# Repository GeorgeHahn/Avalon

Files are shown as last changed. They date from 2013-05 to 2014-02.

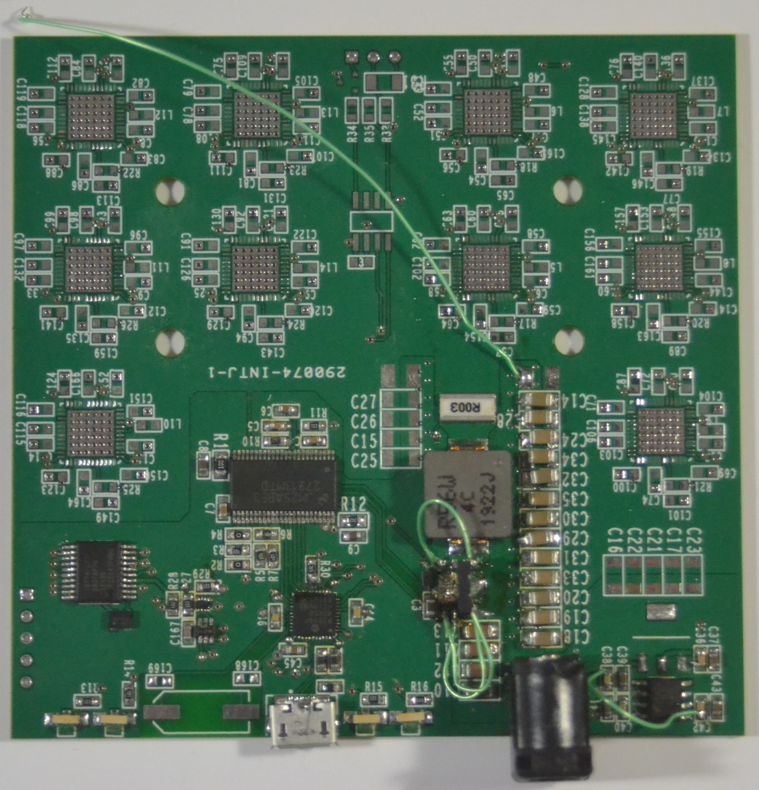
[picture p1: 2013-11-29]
img_top.JPG

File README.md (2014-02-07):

Avalon
========

Public Domain Bitcoin ASIC Miner Project

Firmware and driver based on Klondike Project

Donations: 14kf3rM66cLMrhR3eXHMjh4B5W5Xko1jJr

First prototype

## SUMMARY

  This is an open source effort to design and build a Bitcoin mining board based on the second generation Avalon ASIC. The final goal is to have a small board that holds 10 ASIC chips. This board can be controlled via USB communication. An example host would be a PC, Raspberry Pi or TP-Link WR703N router. The host will run cgminer with a custom driver based on the Klondike one and control the board via USB.

  A 10 chip board should be capable of 15000 MH/s and consume about 30W of power. Alternatively, the switching power supply onboard can be turned to a lower voltage, trading hashrate for power efficiency. The supply is variable from 0.700V to 1.708V. Each board can be easily powered by a low cost power adapter, like [this](http://www.amazon.com/gp/product/B005IUV60U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).

  Power for this board is supplied via a barrel jack connector (2.5mm ID, 5.5mm OD). For future revisions, Molex PCI-e or 4 pin power connectors may be added. Another limit on the first revision design is the data connection - these boards are USB only for now. In the future, CAN may be added to make it possible to chain multiple miners together.
  
  The design is currently in Cadence OrCAD + Allegro format, but will be completely backported to [Upverter](https://upverter.com/GeorgeHahn/0bb015271a32ca8e/Avalon/) once tested.

## STATUS

 - ☑ Layout
 - ▢ Prototype
  - ☑ PCB - First prototype has arrived
  - ☑ Stencil
  - ☑ Parts
  - ☑ Assembly
  - ▢ Debug first prototype - in progress
  
 - ▢ Initial firmware
  - ▢ Port Klondike firmware to PIC18F45K50
  - ▢ Testing with a Raspberry Pi
  - ▢ Tune settings for unique SMPS

 - ▢ Future
  - ▢ Try a prototype with metal substrate board (for better heat dissipation)
  - ▢ Measure current on 3.3v and 5v rails; switch to switching regulators if current is significant

## [SCHEMATIC](https://raw.github.com/GeorgeHahn/Avalon/master/hardware/Schematic.pdf) / [LAYOUT](https://github.com/GeorgeHahn/Avalon/tree/master/hardware/allegro/gerbers)
First prototype

## [ISSUES](https://github.com/GeorgeHahn/Avalon/issues)
First prototype has the following issues. Serious issues are bolded, optional improvements are italicized.

 - ▢ [#2](https://github.com/GeorgeHahn/Avalon/issues/2) **Switching FET (U21) has an incorrect footprint**
 - ▢ [#3](https://github.com/GeorgeHahn/Avalon/issues/3) **D1 and Q1 have suboptimal footprints**
 - ▢ [#4](https://github.com/GeorgeHahn/Avalon/issues/4) **C1 and C2 have incorrectly sized footprints**
 - ☑ [#5](https://github.com/GeorgeHahn/Avalon/issues/5) **Ground for some pins on U5 are not connected**
 - ▢ [#6](https://github.com/GeorgeHahn/Avalon/issues/6) Vcore SMPS overvoltage level should be set to A3255 maximum voltage (set by R3)
 - ☑ [#7](https://github.com/GeorgeHahn/Avalon/issues/7) Via-in-pads can be eliminated
 - ☑ [#8](https://github.com/GeorgeHahn/Avalon/issues/8) Status LEDs and D1 don't have polarity indicators on silkscreen
 - ▢ [#9](https://github.com/GeorgeHahn/Avalon/issues/9) Some parts are missing silkscreen reference designators
 - ☑ [#10](https://github.com/GeorgeHahn/Avalon/issues/10) The 3.3v regulator should take 5v input rather than VIN or be switched to a regulator that can handle higher input voltage
 - ▢ [#11](https://github.com/GeorgeHahn/Avalon/issues/11) *Barrel jack is a through hole part, should be switched to SMT*
 - ▢ [#12](https://github.com/GeorgeHahn/Avalon/issues/12) *Should have more input capacitors*
 - ▢ [#13](https://github.com/GeorgeHahn/Avalon/issues/13) *Should switch away from micro USB connectors for improved durability*
 - ☑ *Location for C2, C25-27, C15 is suboptimal*

## WARNINGS

  This project has an advanced switched mode power supply that can supply between 0.700V and 1.708V. NEVER set the SMPS above the Avalon ASICs' rated maximum voltage.

  This project is incomplete and in progress. There may be errors, mistakes, incomplete portions at this time. Do NOT use these project files to order circuit boards until they have been finished and confirmed to work.
  
  See LICENSE and COPYING files for terms and warranty disclaimer.
  
  See RELEASE NOTES for known problems, and issues.

## THANKS

Special thanks to [CUI Inc](http://www.cui.com/) for going the extra mile to get me a sample of their PJ-037BH connector. Thanks to TI for samples of ICs used in the SMPS module. Thanks to AVX for samples of the SMPS output capacitors.

Bitdeli Badge (https://bitdeli.com/free "Bitdeli Badge")

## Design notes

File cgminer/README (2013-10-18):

This is a multi-threaded multi-pool GPU, FPGA and ASIC miner with ATI GPU
monitoring, (over)clocking and fanspeed support for bitcoin and derivative
coins. Do not use on multiple block chains at the same time!

This code is provided entirely free of charge by the programmer in his spare
time so donations would be greatly appreciated. Please consider donating to the
address below.

Con Kolivas <kernel@kolivas.org>
15qSxP1SQcUX3o4nhkfdbgyoWEFMomJ4rZ

DOWNLOADS:

http://ck.kolivas.org/apps/cgminer

GIT TREE:

https://github.com/ckolivas/cgminer

Support thread:

http://bitcointalk.org/index.php?topic=28402.0

IRC Channel:

irc://irc.freenode.net/cgminer

License: GPLv3.  See COPYING for details.

SEE ALSO API-README, ASIC-README, FGPA-README, GPU-README AND SCRYPT-README FOR
MORE INFORMATION ON EACH.

---

EXECUTIVE SUMMARY ON USAGE:

After saving configuration from the menu, you do not need to give cgminer any
arguments and it will load your configuration.

Any configuration file may also contain a single
	"include" : "filename"
to recursively include another configuration file.
Writing the configuration will save all settings from all files in the output.

Single pool:

cgminer -o http://pool:port -u username -p password

Multiple pools:

cgminer -o http://pool1:port -u pool1username -p pool1password -o http://pool2:port -u pool2usernmae -p pool2password

Single pool with a standard http proxy, regular desktop:

cgminer -o "http:proxy:port|http://pool:port" -u username -p password

Single pool with a socks5 proxy, regular desktop:

cgminer -o "socks5:proxy:port|http://pool:port" -u username -p password

Single pool with stratum protocol support:

cgminer -o stratum+tcp://pool:port -u username -p password

The list of proxy types are:
 http:    standard http 1.1 proxy
 http0:   http 1.0 proxy
 socks4:  socks4 proxy
 socks5:  socks5 proxy
 socks4a: socks4a proxy
 socks5h: socks5 proxy using a hostname

If you compile cgminer with a version of CURL before 7.19.4 then some of the above will
not be available. All are available since CURL version 7.19.4

If you specify the --socks-proxy option to cgminer, it will only be applied to all pools
that don't specify their own proxy setting like above

---
BUILDING CGMINER

Dependencies:
	curl dev library 	http://curl.haxx.se/libcurl/
	(libcurl4-openssl-dev)

	curses dev library
	(libncurses5-dev or libpdcurses on WIN32)

	pkg-config		http://www.freedesktop.org/wiki/Software/pkg-config
	libtool			http://www.gnu.org/software/libtool/

	jansson			http://www.digip.org/jansson/
	(jansson is included in-tree and not necessary)

	AMD APP SDK		http://developer.amd.com/sdks/AMDAPPSDK
	(This sdk is mandatory for GPU mining)

	AMD ADL SDK		http://developer.amd.com/sdks/ADLSDK
	(This sdk is mandatory for ATI GPU monitoring & clocking)

	libudev headers
	(This is only required for ASIC+FPGA auto-detection and is linux only)

	libusb headers
	(This is only required for ASIC+FPGA support)

CGMiner specific configuration options:
	--disable-opencl        Override detection and disable building with opencl
	--disable-adl           Override detection and disable building with adl
	--enable-bflsc          Compile support for BFL ASICs (default disabled)
	--enable-klondike       Compile support for Klondike (default disabled)		
	--enable-bitforce       Compile support for BitForce FPGAs(default disabled)
	--enable-icarus         Compile support for Icarus bitstream FPGAs(default disabled)
	--enable-modminer       Compile support for ModMiner FPGAs(default disabled)
	--enable-ztex           Compile support for Ztex Board(default disabled)
	--enable-avalon         Compile support for Avalon (default disabled)
	--enable-scrypt         Compile support for scrypt litecoin mining (default disabled)
	--without-curses        Compile support for curses TUI (default enabled)

Basic *nix build instructions:
	To actually build:

	./autogen.sh	# only needed if building from git repo
	CFLAGS="-O2 -Wall -march=native" ./configure <options>

	No installation is necessary. You may run cgminer from the build
	directory directly.

Native WIN32 build instructions: see windows-build.txt

---

Usage instructions:  Run "cgminer --help" to see options:

Usage: . [-atDdGCgIKklmpPQqrRsTouvwOchnV] 
Options for both config file and command line:
--api-allow         Allow API access (if enabled) only to the given list of [W:]IP[/Prefix] address[/subnets]
                    This overrides --api-network and you must specify 127.0.0.1 if it is required
                    W: in front of the IP address gives that address privileged access to all api commands
--api-description   Description placed in the API status header (default: cgminer version)
--api-groups        API one letter groups G:cmd:cmd[,P:cmd:*...]
                    See API-README for usage
--api-listen        Listen for API requests (default: disabled)
                    By default any command that does not just display data returns access denied
                    See --api-allow to overcome this
--api-network       Allow API (if enabled) to listen on/for any address (default: only 127.0.0.1)
--api-port          Port number of miner API (default: 4028)
--auto-fan          Automatically adjust all GPU fan speeds to maintain a target temperature
--auto-gpu          Automatically adjust all GPU engine clock speeds to maintain a target temperature
--balance           Change multipool strategy from failover to even share balance
--benchmark         Run cgminer in benchmark mode - produces no shares
--compact           Use compact display without per device statistics
--debug|-D          Enable debug output
--device|-d <arg>   Select device to use, one value, range and/or comma separated (e.g. 0-2,4) default: all
--disable-rejecting Automatically disable pools that continually reject shares
--expiry|-E <arg>   Upper bound on how many seconds after getting work we consider a share from it stale (default: 120)
--failover-only     Don't leak work to backup pools when primary pool is lagging
--fix-protocol      Do not redirect to a different getwork protocol (eg. stratum)
--hotplug <arg>     Set hotplug check time to <arg> seconds (0=never default: 5) - only with libusb
--kernel-path|-K <arg> Specify a path to where bitstream and kernel files are (default: "/usr/local/bin")
--load-balance      Change multipool strategy from failover to efficiency based balance
--log|-l <arg>      Interval in seconds between log output (default: 5)
--lowmem            Minimise caching of shares for low memory applications
--monitor|-m <arg>  Use custom pipe cmd for output messages
--net-delay         Impose small delays in networking to not overload slow routers
--no-submit-stale   Don't submit shares if they are detected as stale
--pass|-p <arg>     Password for bitcoin JSON-RPC server
--per-device-stats  Force verbose mode and output per-device statistics
--protocol-dump|-P  Verbose dump of protocol-level activities
--queue|-Q <arg>    Minimum number of work items to have queued (0 - 10) (default: 1)
--quiet|-q          Disable logging output, display status and errors
--real-quiet        Disable all output
--remove-disabled   Remove disabled devices entirely, as if they didn't exist
--rotate <arg>      Change multipool strategy from failover to regularly rotate at N minutes (default: 0)
--round-robin       Change multipool strategy from failover to round robin on failure
--scan-time|-s <arg> Upper bound on time spent scanning current work, in seconds (default: 60)
--sched-start <arg> Set a time of day in HH:MM to start mining (a once off without a stop time)
--sched-stop <arg>  Set a time of day in HH:MM to stop mining (will quit without a start time)
--scrypt            Use the scrypt algorithm for mining (litecoin only)
--sharelog <arg>    Append share log to file
--shares <arg>      Quit after mining N shares (default: unlimited)
--socks-proxy <arg> Set socks4 proxy (host:port) for all pools without a proxy specified
--syslog            Use system log for output messages (default: standard error)
--temp-cutoff <arg> Temperature where a device will be automatically disabled, one value or comma separated list (default: 95)
--text-only|-T      Disable ncurses formatted screen output
--url|-o <arg>      URL for bitcoin JSON-RPC server
--user|-u <arg>     Username for bitcoin JSON-RPC server
--verbose           Log verbose output to stderr as well as status output
--userpass|-O <arg> Username:Password pair for bitcoin JSON-RPC server
Options for command line only:
--config|-c <arg>   Load a JSON-format configuration file
See example.conf for an example configuration.
--help|-h           Print this message
--version|-V        Display version and exit

GPU only options:

--auto-fan          Automatically adjust all GPU fan speeds to maintain a target temperature
--auto-gpu          Automatically adjust all GPU engine clock speeds to maintain a target temperature
--disable-gpu|-G    Disable GPU mining even if suitable devices exist
--gpu-threads|-g <arg> Number of threads per GPU (1 - 10) (default: 2)
--gpu-dyninterval <arg> Set the refresh interval in ms for GPUs using dynamic intensity (default: 7)
--gpu-engine <arg>  GPU engine (over)clock range in Mhz - one value, range and/or comma separated list (e.g. 850-900,900,750-850)
--gpu-fan <arg>     GPU fan percentage range - one value, range and/or comma separated list (e.g. 25-85,85,65)
--gpu-map <arg>     Map OpenCL to ADL device order manually, paired CSV (e.g. 1:0,2:1 maps OpenCL 1 to ADL 0, 2 to 1)
--gpu-memclock <arg> Set the GPU memory (over)clock in Mhz - one value for all or separate by commas for per card.
--gpu-memdiff <arg> Set a fixed difference in clock speed between the GPU and memory in auto-gpu mode
--gpu-powertune <arg> Set the GPU powertune percentage - one value for all or separate by commas for per card.
--gpu-reorder       Attempt to reorder GPU devices according to PCI Bus ID
--gpu-vddc <arg>    Set the GPU voltage in Volts - one value for all or separate by commas for per card.
--intensity|-I <arg> Intensity of GPU scanning (d or -10 -> 10, default: d to maintain desktop interactivity)
--kernel|-k <arg>   Override kernel to use (diablo, poclbm, phatk or diakgcn) - one value or comma separated
--ndevs|-n          Enumerate number of detected GPUs and exit
--no-restart        Do not attempt to restart GPUs that hang
--temp-hysteresis <arg> Set how much the temperature can fluctuate outside limits when automanaging speeds (default: 3)
--temp-overheat <arg> Overheat temperature when automatically managing fan and GPU speeds (default: 85)
--temp-target <arg> Target temperature when automatically managing fan and GPU speeds (default: 75)
--vectors|-v <arg>  Override detected optimal vector (1, 2 or 4) - one value or comma separated list
--worksize|-w <arg> Override detected optimal worksize - one value or comma separated list

See GPU-README for more information regarding GPU mining.

SCRYPT only options:

--lookup-gap <arg>  Set GPU lookup gap for scrypt mining, comma separated
--shaders <arg>     GPU shaders per card for tuning scrypt, comma separated
--thread-concurrency <arg> Set GPU thread concurrency for scrypt mining, comma separated

See SCRYPT-README for more information regarding litecoin mining.

ASIC and FPGA mining boards (BFL ASIC, BitForce, Icarus, ModMiner, Ztex)
only options:

--avalon-auto       Adjust avalon overclock frequency dynamically for best hashrate
--avalon-fan <arg> Set fanspeed percentage for avalon, single value or range (default: 20-100)
--avalon-freq <arg> Set frequency range for avalon-auto, single value or range
--avalon-cutoff <arg> Set avalon overheat cut off temperature (default: 60)
--avalon-options <arg> Set avalon options baud:miners:asic:timeout:freq
--avalon-temp <arg> Set avalon target temperature (default: 50)
--bfl-range         Use nonce range on bitforce devices if supported
--icarus-options <arg> Set specific FPGA board configurations - one set of values for all or comma separated
--icarus-timing <arg> Set how the Icarus timing is calculated - one setting/value for all or comma separated
--usb <arg>         USB device selection (See below)
--usb-dump          (See FPGA-README)

See FGPA-README and ASIC-README for more information regarding these.

Cgminer should automatically find all of your Avalon ASIC, BFL ASIC, BitForce
FPGAs, Icarus bitstream FPGAs, ASICMINER usb block erupters, ModMiner FPGAs,
or Ztex FPGAs

---

USB DEVICES

WINDOWS:

On windows, the direct USB support requires the installation of a WinUSB
driver (NOT the ftdi_sio driver), and attach it to your devices.
The easiest way to do this is to use the zadig utility which will install the
drivers for you and then once you plug in your device you can choose the
"list all devices" from the "option" menu and you should be able to see the
device as something like: "BitFORCE SHA256 SC". Choose the install or replace
driver option and select WinUSB. You can either google for zadig or download
it from the cgminer directoy in the DOWNLOADS link above.

LINUX:

On linux, the direct USB support requires no drivers at all. However due to
permissions issues, you may not be able to mine directly on the devices as a
regular user without giving the user access to the device or by mining as
root (administrator). In order to give your regular user access, you can make
him a member of the plugdev group with the following commands:

 sudo usermod -G plugdev -a `whoami`

If your distribution does not have the plugdev group you can create it with:

 sudo groupadd plugdev

In order for the BFL devices to instantly be owned by the plugdev group and
accessible by anyone from the plugdev group you can copy the file
"01-cgminer.rules" from the cgminer archive into the /etc/udev/rules.d
directory with the following command:

 sudo cp 01-cgminer.rules /etc/udev/rules.d/

After this you can either manually restart udev and re-login, or more easily
just reboot.

Advanced USB options:

The --usb option can restrict how many Avalon, BFL ASIC, BitForce FPGAs,
ModMiner FPGAs or Icarus bitstream FPGAs it finds:

  --usb 1:2,1:3,1:4,1:*
or
  --usb BAS:1,BFL:1,MMQ:0,ICA:0
or
  --usb :10

You can only use one of the above 3

The first version
  --usb 1:2,1:3,1:4,1:*
allows you to select which devices to mine on with a list of USB
 bus_number:device_address
All other USB devices will be ignored
Hotplug will also only look at the devices matching the list specified and
find nothing new if they are all in use
You can specify just the USB bus_number to find all devices like 1:*
which means any devices on USB bus_number 1
This is useful if you unplug a device then plug it back in the same port,
it usually reappears with the same bus_number but a different device_address

You can see the list of all USB devices on linux with 'sudo lsusb'
Cgminer will list the recognised USB devices with the '-n' option or the
'--usb-dump 0' option
The '--usb-dump N' option with a value of N greater than 0 will dump a lot
of details about each recognised USB device
If you wish to see all USB devices, include the --usb-list-all option

The second version
  --usb BAS:1,BFL:1,MMQ:0,ICA:0
allows you to specify how many devices to choose based on each device
driver cgminer has - there are currently 4 USB drivers: BAS, BFL, MMQ & ICA
N.B. you can only specify which device driver to limit, not the type of
each device, e.g. with BAS:n you can limit how many BFL ASIC devices will
be checked, but you cannot limit the number of each type of BFL ASIC
Also note that the MMQ count is the number of MMQ backplanes you have
not the number of MMQ FPGAs

The third version
  --usb :10
means only use a maximum of 10 devices of any supported USB devices
Once cgminer has 10 devices it will not configure any more and hotplug will
not scan for any more
If one of the 10 devices stops working, hotplug - if enabled, as is default
- will scan normally again until it has 10 devices

  --usb :0 will disable all USB I/O other than to initialise libusb

NOTE: The --device option will limit which devices are in use based on their
numbering order of the total devices, so if you hotplug USB devices regularly,
it will not reliably be the same devices.

---

WHILE RUNNING:

The following options are available while running with a single keypress:

[P]ool management [G]PU management [S]ettings [D]isplay options [Q]uit

P gives you:

Current pool management strategy: Failover
[F]ailover only disabled
[A]dd pool [R]emove pool [D]isable pool [E]nable pool
[C]hange management strategy [S]witch pool [I]nformation

S gives you:

[Q]ueue: 1
[S]cantime: 60
[E]xpiry: 120
[W]rite config file
[C]gminer restart

D gives you:

[N]ormal [C]lear [S]ilent mode (disable all output)
[D]ebug:off
[P]er-device:off
[Q]uiet:off
[V]erbose:off
[R]PC debug:off
[W]orkTime details:off
co[M]pact: off
[L]og interval:5

Q quits the application.

G gives you something like:

GPU 0: [124.2 / 191.3 Mh/s] [A:77  R:33  HW:0  U:1.73/m  WU 1.73/m]
Temp: 67.0 C
Fan Speed: 35% (2500 RPM)
Engine Clock: 960 MHz
Memory Clock: 480 Mhz
Vddc: 1.200 V
Activity: 93%
Powertune: 0%
Last initialised: [2011-09-06 12:03:56]
Thread 0: 62.4 Mh/s Enabled ALIVE
Thread 1: 60.2 Mh/s Enabled ALIVE

[E]nable [D]isable [R]estart GPU [C]hange settings
Or press any other key to continue

The running log shows output like this:

 [2012-10-12 18:02:20] Accepted f0c05469 Diff 1/1 GPU 0 pool 1
 [2012-10-12 18:02:22] Accepted 218ac982 Diff 7/1 GPU 1 pool 1
 [2012-10-12 18:02:23] Accepted d8300795 Diff 1/1 GPU 3 pool 1
 [2012-10-12 18:02:24] Accepted 122c1ff1 Diff 14/1 GPU 1 pool 1

The 8 byte hex value are the 2nd 8 bytes of the share being submitted to the
pool. The 2 diff values are the actual difficulty target that share reached
followed by the difficulty target the pool is currently asking for.

---
Also many issues and FAQs are covered in the forum thread
dedicated to this program,
	http://forum.bitcoin.org/index.php?topic=28402.0

The output line shows the following:
(5s):1713.6 (avg):1707.8 Mh/s | A:729  R:8  HW:0  WU:22.53/m

Each column is as follows:
5s:  A 5 second exponentially decaying average hash rate
avg: An all time average hash rate
A:  The total difficulty of Accepted shares
R:  The total difficulty of Rejected shares
HW:  The number of HardWare errors
WU:  The Work Utility defined as the number of diff1 shares work / minute
     (accepted or rejected).

 GPU 1: 73.5C 2551RPM | 427.3/443.0Mh/s | A:8 R:0 HW:0 WU:4.39/m

Each column is as follows:
Temperature (if supported)
Fanspeed (if supported)
A 5 second exponentially decaying average hash rate
An all time average hash rate
The total difficulty of accepted shares
The total difficulty of rejected shares
The number of hardware erorrs
The work utility defined as the number of diff1 shares work / minute

The cgminer status line shows:
 ST: 1  SS: 0  NB: 1  LW: 8  GF: 1  RF: 1

ST is STaged work items (ready to use).
SS is Stale Shares discarded (detected and not submitted so don't count as rejects)
NB is New Blocks detected on the network
LW is Locally generated Work items
GF is Getwork Fail Occasions (server slow to provide work)
RF is Remote Fail occasions (server slow to accept work)

The block display shows:
Block: 0074c5e482e34a506d2a051a...  Started: [17:17:22]  Best share: 2.71K

This shows a short stretch of the current block, when the new block started,
and the all time best difficulty share you've found since starting cgminer
this time.

---
MULTIPOOL

FAILOVER STRATEGIES WITH MULTIPOOL:
A number of different strategies for dealing with multipool setups are
available. Each has their advantages and disadvantages so multiple strategies
are available by user choice, as per the following list:

FAILOVER:
The default strategy is failover. This means that if you input a number of
pools, it will try to use them as a priority list, moving away from the 1st
to the 2nd, 2nd to 3rd and so on. If any of the earlier pools recover, it will
move back to the higher priority ones.

ROUND ROBIN:
This strategy only moves from one pool to the next when the current one falls
idle and makes no attempt to move otherwise.

ROTATE:
This strategy moves at user-defined intervals from one active pool to the next,
skipping pools that are idle.

LOAD BALANCE:
This strategy sends work to all the pools to maintain optimum load. The most
efficient pools will tend to get a lot more shares. If any pool falls idle, the
rest will tend to take up the slack keeping the miner busy.

BALANCE:
This strategy monitors the amount of difficulty 1 shares solved for each pool
and uses it to try to end up doing the same amount of work for all pools.

---
LOGGING

cgminer will log to stderr if it detects stderr is being redirected to a file.
To enable logging simply add 2>logfile.txt to your command line and logfile.txt
will contain the logged output at the log level you specify (normal, verbose,
debug etc.)

In other words if you would normally use:
./cgminer -o xxx -u yyy -p zzz
if you use
./cgminer -o xxx -u yyy -p zzz 2>logfile.txt
it will log to a file called logfile.txt and otherwise work the same.

There is also the -m option on linux which will spawn a command of your choice
and pipe the output directly to that command.

The WorkTime details 'debug' option adds details on the end of each line
displayed for Accepted or Rejected work done. An example would be:

 <-00000059.ed4834a3 M:X D:1.0 G:17:02:38:0.405 C:1.855 (2.995) W:3.440 (0.000) S:0.461 R:17:02:47

The first 2 hex codes are the previous block hash, the rest are reported in
seconds unless stated otherwise:
The previous hash is followed by the getwork mode used M:X where X is one of
P:Pool, T:Test Pool, L:LP or B:Benchmark,
then D:d.ddd is the difficulty required to get a share from the work,
then G:hh:mm:ss:n.nnn, which is when the getwork or LP was sent to the pool and
the n.nnn is how long it took to reply,
followed by 'O' on it's own if it is an original getwork, or 'C:n.nnn' if it was
a clone with n.nnn stating how long after the work was recieved that it was cloned,
(m.mmm) is how long from when the original work was received until work started,
W:n.nnn is how long the work took to process until it was ready to submit,
(m.mmm) is how long from ready to submit to actually doing the submit, this is
usually 0.000 unless there was a problem with submitting the work,
S:n.nnn is how long it took to submit the completed work and await the reply,
R:hh:mm:ss is the actual time the work submit reply was received

If you start cgminer with the --sharelog option, you can get detailed
information for each share found. The argument to the option may be "-" for
standard output (not advisable with the ncurses UI), any valid positive number
for that file descriptor, or a filename.

To log share data to a file named "share.log", you can use either:
./cgminer --sharelog 50 -o xxx -u yyy -p zzz 50>share.log
./cgminer --sharelog share.log -o xxx -u yyy -p zzz

For every share found, data will be logged in a CSV (Comma Separated Value)
format:
    timestamp,disposition,target,pool,dev,thr,sharehash,sharedata
For example (this is wrapped, but it's all on one line for real):
    1335313090,reject,
    ffffffffffffffffffffffffffffffffffffffffffffffffffffffff00000000,
    http://localhost:8337,GPU0,0,
    6f983c918f3299b58febf95ec4d0c7094ed634bc13754553ec34fc3800000000,
    00000001a0980aff4ce4a96d53f4b89a2d5f0e765c978640fe24372a000001c5
    000000004a4366808f81d44f26df3d69d7dc4b3473385930462d9ab707b50498
    f681634a4f1f63d01a0cd43fb338000000000080000000000000000000000000
    0000000000000000000000000000000000000000000000000000000080020000

---

RPC API

For RPC API details see the API-README file

---

FAQ

Q: Can I mine on servers from different networks (eg smartcoin and bitcoin) at
the same time?
A: No, cgminer keeps a database of the block it's working on to ensure it does
not work on stale blocks, and having different blocks from two networks would
make it invalidate the work from each other.

Q: Can I configure cgminer to mine with different login credentials or pools
for each separate device?
A: No.

Q: Can I put multiple pools in the config file?
A: Yes, check the example.conf file. Alternatively, set up everything either on
the command line or via the menu after startup and choose settings->write
config file and the file will be loaded one each startup.

Q: The build fails with gcc is unable to build a binary.
A: Remove the "-march=native" component of your CFLAGS as your version of gcc
does not support it.

Q: Can you implement feature X?
A: I can, but time is limited, and people who donate are more likely to get
their feature requests implemented.

Q: Work keeps going to my backup pool even though my primary pool hasn't
failed?
A: Cgminer checks for conditions where the primary pool is lagging and will
pass some work to the backup servers under those conditions. The reason for
doing this is to try its absolute best to keep the GPUs working on something
useful and not risk idle periods. You can disable this behaviour with the
option --failover-only.

Q: Is this a virus?
A: Cgminer is being packaged with other trojan scripts and some antivirus
software is falsely accusing cgminer.exe as being the actual virus, rather
than whatever it is being packaged with. If you installed cgminer yourself,
then you do not have a virus on your computer. Complain to your antivirus
software company. They seem to be flagging even source code now from cgminer
as viruses, even though text source files can't do anything by themself.

Q: Can you modify the display to include more of one thing in the output and
less of another, or can you change the quiet mode or can you add yet another
output mode?
A: Everyone will always have their own view of what's important to monitor.
The defaults are very sane and I have very little interest in changing this
any further.

Q: What are the best parameters to pass for X pool/hardware/device.
A: Virtually always, the DEFAULT parameters give the best results. Most user
defined settings lead to worse performance. The ONLY thing most users should
need to set is the Intensity for GPUs.

Q: What happened to CPU mining?
A: Being increasingly irrelevant for most users, and a maintenance issue, it is
no longer under active development and will not be supported. No binary builds
supporting CPU mining will be released. Virtually all remaining users of CPU
mining are as back ends for illegal botnets. The main reason cgminer is being
inappopriately tagged as a virus by antivirus software is due to the trojans
packaging a CPU mining capable version of it. There is no longer ANY CPU mining
code in cgminer. If you are mining bitcoin with CPU today, you are spending
1000x more in electricity costs than you are earning in bitcoin.

Q: GUI version?
A: No. The RPC interface makes it possible for someone else to write one
though.

Q: I'm having an issue. What debugging information should I provide?
A: Start cgminer with your regular commands and add -D -T --verbose and provide
the full startup output and a summary of your hardware, operating system, ATI
driver version and ATI stream version.

Q: Why don't you provide win64 builds?
A: Win32 builds work everywhere and there is precisely zero advantage to a
64 bit build on windows.

Q: Is it faster to mine on windows or linux?
A: It makes no difference. It comes down to choice of operating system for
their various features. Linux offers much better long term stability and
remote monitoring and security, while windows offers you overclocking tools
that can achieve much more than cgminer can do on linux.

Q: Can I mine with cgminer on a MAC?
A: cgminer will compile on OSX, but the performance of GPU mining is
compromised due to the opencl implementation on OSX, there is no temperature
or fanspeed monitoring, and the cooling design of most MACs, despite having
powerful GPUs, will usually not cope with constant usage leading to a high
risk of thermal damage. It is highly recommended not to mine on a MAC unless
it is to a USB device.

Q: I'm trying to mine litecoin but cgminer shows MH values instead of kH and
submits no shares?
A: Add the --scrypt parameter.

Q: I switch users on windows and my mining stops working?
A: That's correct, it does. It's a permissions issue that there is no known
fix for due to monitoring of GPU fanspeeds and temperatures. If you disable
the monitoring with --no-adl it should switch okay.

Q: My network gets slower and slower and then dies for a minute?
A; Try the --net-delay option.

Q: How do I tune for p2pool?
A: p2pool has very rapid expiration of work and new blocks, it is suggested you
decrease intensity by 1 from your optimal value, and decrease GPU threads to 1
with -g 1. It is also recommended to use --failover-only since the work is
effectively like a different block chain. If mining with a minirig, it is worth
adding the --bfl-range option.

Q: Are OpenCL kernels from other mining software useable in cgminer?
A: No, the APIs are slightly different between the different software and they
will not work.

Q: I run PHP on windows to access the API with the example miner.php. Why does
it fail when php is installed properly but I only get errors about Sockets not
working in the logs?
A: http://us.php.net/manual/en/sockets.installation.php

Q: What is a PGA?
A: At the moment, cgminer supports 4 FPGAs: BitForce, Icarus, ModMiner, and Ztex.
They are Field-Programmable Gate Arrays that have been programmed to do Bitcoin
mining. Since the acronym needs to be only 3 characters, the "Field-" part has
been skipped.

Q: What is an ASIC?
A: Cgminer currently supports 2 ASICs: Avalon and BitForce SC devices. They
are Application Specify Integrated Circuit devices and provide the highest
performance per unit power due to being dedicated to only one purpose.

Q: Can I mine scrypt with FPGAs or ASICs?
A: No.

Q: What is stratum and how do I use it?
A: Stratum is a protocol designed for pooled mining in such a way as to
minimise the amount of network communications, yet scale to hardware of any
speed. With versions of cgminer 2.8.0+, if a pool has stratum support, cgminer
will automatically detect it and switch to the support as advertised if it can.
Stratum uses direct TCP connections to the pool and thus it will NOT currently
work through a http proxy but will work via a socks proxy if you need to use
one. If you input the stratum port directly into your configuration, or use the
special prefix "stratum+tcp://" instead of "http://", cgminer will ONLY try to
use stratum protocol mining. The advantages of stratum to the miner are no
delays in getting more work for the miner, less rejects across block changes,
and far less network communications for the same amount of mining hashrate. If
you do NOT wish cgminer to automatically switch to stratum protocol even if it
is detected, add the --fix-protocol option.

Q: Why don't the statistics add up: Accepted, Rejected, Stale, Hardware Errors,
Diff1 Work, etc. when mining greater than 1 difficulty shares?
A: As an example, if you look at 'Difficulty Accepted' in the RPC API, the number
of difficulty shares accepted does not usually exactly equal the amount of work
done to find them. If you are mining at 8 difficulty, then you would expect on
average to find one 8 difficulty share, per 8 single difficulty shares found.
However, the number is actually random and converges over time, it is an average,
not an exact value, thus you may find more or less than the expected average.

Q: Why do the scrypt diffs not match with the current difficulty target?
A: The current scrypt block difficulty is expressed in terms of how many
multiples of the BTC difficulty it currently is (eg 28) whereas the shares of
"difficulty 1" are actually 65536 times smaller than the BTC ones. The diff
expressed by cgminer is as multiples of difficulty 1 shares.

Q: Can I make a donation in litecoin?
A: Yes, see SCRYPT-README for the address, but the author prefers bitcoin if
possible.

Q: My keyboard input momentarily pauses or repeats keys every so often on
windows while mining?
A: The USB implementation on windows can be very flaky on some hardware and
every time cgminer looks for new hardware to hotplug it it can cause these
sorts of problems. You can disable hotplug with:
--hotplug 0

Q: Can I use a proxy?
A: Proxies only work with the getwork and GBT protocols using the --proxy
command. If you wish to use a proxy with stratum, people have supported
success with various 3rd party tools like proxifier.

Q: What should my Work Utility (WU) be?
A: Work utility is the product of hashrate * luck and only stabilises over a
very long period of time. Assuming all your work is valid work, bitcoin mining
should produce a work utility of approximately 1 per 71.6MH. This means at
5GH you should have a WU of 5000 / 71.6 or ~ 69. You cannot make your machine
do "better WU" than this - it is luck related. However you can make it much
worse if your machine produces a lot of hardware errors producing invalid work.

---

This code is provided entirely free of charge by the programmer in his spare
time so donations would be greatly appreciated. Please consider donating to the
address below.

Con Kolivas <kernel@kolivas.org>
15qSxP1SQcUX3o4nhkfdbgyoWEFMomJ4rZ

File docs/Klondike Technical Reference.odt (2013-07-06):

Klondike Technical Reference

This document describes technical details and operation of the Klondike Bitcoin miners.

There are currently three related but different designs:

K1 (Nano) - a small USB dongle containing one Avalon ASIC.

K16 - a medium size 10cm x 10cm board containing 16 Avalon ASICs.

K64 - a 4-up chained panelization of the K16 design, 20cm x 20cm.

These designs are based on a PIC16LF1459 micro-controller with USB connectivity. This device is low-cost and has enough functionality to handle all the tasks required.

The following PIC hardware functions are utilized in the Klondike:

USB engine – with software stack support, provides for host control.

I2C engine – simple bus to communicate with chained boards.

USART – used to receive result data from the ASICs on board.

Timer0 – provide timing for ASIC work progress and housekeeping.

Timer1 – measure fan tachometer output for fan speed (K16,K64).

Timer2,PWM – provide fan speed control (K16,K64).

Temperature Sensor – for monitoring successful heat dissipation.

ADC – for measuring an external thermistor, as above (K16, K64).

I/O pins – send data to the ASIC chain, enable clock, drive an LED indicator.

Upon device start up the PIC is programmed to attach to a USB host as a device with serial emulation. If it cannot detect a USB host then it falls back on I2C for host control. It monitors both these channels until it can begin operation which consists of accepting commands from it's host master. These commands are described in detail in this document.

In addition to the PIC controller the Klondike board also contains suitable regulated power and primary clock generation for the ASICs on board. This consists of 1.2V core power, 3.3V I/O and PIC power, and 1.2V clock generator power. The 1.2V core and 3.3V power are provided using buck regulator switching technology. The 1.2V clock generator supply is provided by a linear regulator to isolate it from the core supply. The clock is provided by a high precision oscillator package, or optionally from the internal PIC clock generator.

The K1 design uses a buck regulator only for the 1.2V core supply. The other two supplies are provided by linear regulation. All three are derived from the USB 5V supply. The K16 / K64 source power from a 12V ATX type power supply.

PIC16LF1459 Pin Allocation

The following table indicates the use allocated to each PIC I/O pin.

Pin# | Name | Klondike Usage
19 | RA0 | USB D+
18 | RA1 | USB D-
4 | RA3 | Fan tachometer sense input (also MCLR to program)
3 | RA4 | CLK_EN enable ASIC clock (optionally CLK_OUT)
2 | RA5 | Drives LED for activity indication
13 | RB4 | I2C data to slaves (SDA)
12 | RB5 | ASIC REPORT data input (both banks)
11 | RB6 | I2C clock to slaves (SCL)
10 | RB7 | ASIC REPORT clock input (both banks)
16 | RC0 | ICSPDAT – programming data (otherwise unused)
15 | RC1 | ICSPCLK – programming clock (otherwise unused)
14 | RC2 | Analog input for Thermistor voltage
7 | RC3 | DIN_9N – config data to ASIC bank 2 - P
6 | RC4 | DIN_9P – config data to ASIC bank 2 - N
5 | RC5 | PWM output to control fan via Power MOSFET
8 | RC6 | DIN_6N – config data to ASIC bank 1 - P
9 | RC7 | DIN_6P – config data to ASIC bank 1 - N

Two Klondike board variants support either the SSOP 20-pin or QFN 20-pin packages.

Klondike Command Protocol

The Klondike device chain is controlled by a host master using a simple command protocol. Each command consists of:

<cmd> single char <address> 1 byte, followed any required data.

<address> is a single byte binary ID ranging from 0 up to <slaves>, and is always the first parameter after a command. Not shown in the table below for brevity.

Replies also start with the same <cmd><address> pattern, not shown.

Command | Code | Data | Reply
Identity | I | None. | <version><serial><product>
Status | S | None. | <state><chips><slaves><workque> <workid><temp><fanspeed> <hashcount><errorcount>
Config | C | <hashclock><temp target><temp critical><fan speed> or 0 binary to query only. | Updated data echoed back.
Work | W | <workid><midstate><data> | returns same as Status command
Abort | A | None. | returns same as Status command
Enable | E | 1 or 0 | returns same as Status command
Result | = | None (not sent by host). | <workid><nonce>

The following data values are used above:

Name | Data Type | Value
<version> | 1 byte, binary | Protocol Version: high nibble:major, low nibble:minor
<serial> | 4 byte, binary | Unique serial# as 32bit word.
<product> | StringZ. | Product Identifier eg. K1, K16, K64. Zero terminated. Max 8 chars.
<state> | 1 character | I (initializing), R (ready for work), W (working), D (disabled).
<chips> | 1 byte, binary | Count of chips on board (1 - 64).
<slaves> | 1 byte, binary | Count of slaves connected to this board (0 – 112).
<workqc> | 1 byte, binary | Number of work items in queue including current active job.
<temp> | 1 byte, binary | Temperature value. Needs conversion to degC via calc or lookup table.
<fan speed> | 1 byte, binary | Fan speed. Count of ticks for tach high period.
<hashclock> | 2 bytes, binary | ASIC clock speed in 0.5 MHz steps, eg. 600 => 300MHz
<temp target> | 1 byte, binary | Temperature to maintain by adjusting fan speed. See temp conversion info.
<temp critical> | 1 byte, binary | Temperature above which to disable work.
<fan speed> | 1 byte, binary | Force fan speed, value 0-255 controls power to fan.
<workid> | 1 byte, binary | Work ID, unique per device address.
<midstate> | 32 bytes, binary | Midstate value to hash.
<data> | 12 bytes, binary | Data value to hash.
<hashcount> | 2 bytes, binary | Number of hashes completed as count of 256,000 hash units.
<errorcount> | 2 byte, binary | Number of errors that occurred in result receiver.
<nonce> | 4 bytes, binary | Result value of hashing.

The provided ktest program allows manually testing commands and serves as a working example of very simple code to control the Klondike.

Preliminary Firmware Operation Details

( a more full description will follow once final development is completed )

Temperature

The value returned by protocol data is an analog device reading (ADC) not deg C. A lookup table could be used but also in capable processors a conversion using the natural log function ( ln ) is easy.

From the thermistor datasheet we have,

deg C = 1 / ( 1 / (To + 273.15) + ln(Rt/Ro) / 3987) – 273.15

where To is 25C, Ro is 2200, Rt is the thermistor resistance measured via the voltage divider network and given by

Rt = ADC * 1000 / (256 – ADC) and is independent of reference voltage.

Or, in C code from cgminer klondike driver:

return (double)1/((double)1/(25+273.15) +

log((double)temp*1000/(256-temp)/2200)/3987) - 273.15;

Note that the temperature is read from a thermistor near the U7 ASIC and so is not the internal temperature of the ASIC. An offset value should be applied that estimates the difference. This offset is undetermined at this time.

See the “Thermistor Lookup Table.ods” spreadsheet for example lookup and temperature conversion details.

ASIC Clock

ASIC clock speed is indicated in 0.5 MHz steps – double the MHz rate, eg.

282 → write 564

300 → write 600

Fan Speed

Fan tachometer readings in the status record are the measured high period in 170.667uS ticks. Since the maximum is 255 ticks that means a high period of 43,520 uS. Since there are two tachometer periods per RPM with 50% duty cycle that makes the lowest possible RPM reading,

1/(0.043350 *2 *2) * 60 secs/minute = 345 RPM.

Below this it should report zero as a rollover clears the count.

General equation for RPM is,

RPM = 87890 / count

Hash Timer

The code uses Timer0 as a hash timer to predict when new work should be pushed and time how much work was done if aborted.

Timer0 runs off the instruction clock at 12 MHz with a DIV 256 prescaler, making each count 21.3 uS. A count is loaded into Timer0 depending on ASIC hash clock speed such that each rollover occurs at close to 256,000 hash cycles. This makes counting rollovers as “ticks” useful for counting large hash values to a resolution of 256,000 – and potentially more accurate if the Timer0 value is checked, though that is not currently implemented.

For example, at 282MHz clock a value of (256-42) is set for Timer0 which causes a tick every 896 uS. This corresponds closely with 282,000,000 / 256,000 hashes completed (actually 252,672 hashes). This tick is counted to determine when new work should be pushed to the ASIC chain. The work tick value is dependent on how many ASICs are populated on each board.

The work tick value is also counted up to 256 to provide a “Slow Tick” for various housekeeping tasks such as updating fan speed, temperature and toggling the activity LED.

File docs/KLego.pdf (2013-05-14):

## Klondike 16 / 64 Modular Design

Klondike is designed to fit together in an unlimited tile arrangement. The pin headers located on the K16 board allow using a simple jumper blocks to join units and enable board to board communication without having to deal with cables and wiring hassles. One single mini-USB connector is all that is needed to control the array. Special repeater-jumpers can boost the I2C signal and allow more boards to be attached.

The diagram below shows how K16 units connect, and the flow of control communication via I2C pathways. The large red squares show how a K64 board is really just 4 x K16 already pre-connected on one board. Like a K16 the K64 is designed to also tile, with both other K64 and smaller K16 units.

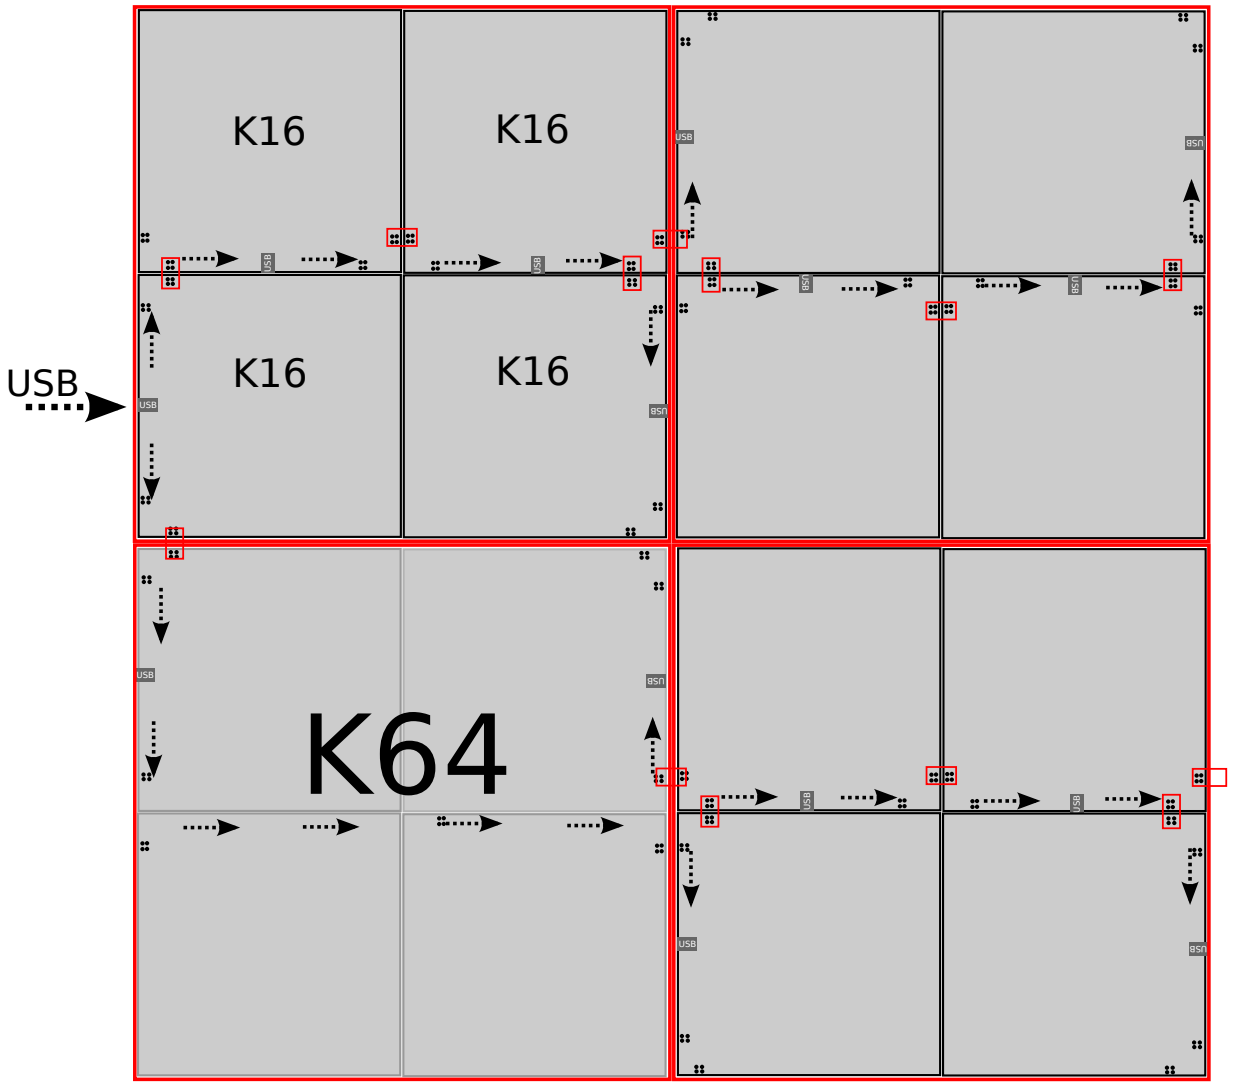
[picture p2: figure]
USB

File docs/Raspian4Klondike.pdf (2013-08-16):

Raspian for Klondike

Build and Install Notes

This SD card is based on the Raspian Server 2.4 image available from:

http://sirlagz.net/tag/raspbian-server-edition/

As indicated on that site I use dd to copy to the SD card, and then login and install packages needed for building and running cgminer. I've added a few other packages I find useful as well for small server monitoring. I've added some script files for auto-start of cgminer on boot up. I've also updated using apt-get upgrade.

After you plug the SD card into your RasPi and boot you will need to detect which IP address it is on. This can usually be found from your router client list or you can use the arp program from another system on the network.

arp a

eg. receive back,
? (10.42.0.83) at b8:27:eb:2e:18:61 [ether] on eth0

ssh pi@10.42.0.83
pwd:raspberry

I have already run the raspi-config program to set locale but you may want to run that program again and adjust any settings for your own use.

I configured the system to work with WiFi as well as basic LAN connections. You can edit your WiFi connection details in /etc/wpa_supplicant/wpa_supplicant.conf if you want to use a WiFi USB dongle for access.

The packages I installed for building cgminer are:

autoconf libtool libncurses-dev curl libcurl4-openssl-dev pkg-config libusb-1.0

I added htop and screen for a nicer process monitor and ease with detached sessions.

I haven't added the main klondike repo and ktest programs as typically those would be more useful on a full desktop for testing/development.

Useful Info:

You may want to change your password after logging in,

passwd

Or use ssh key authentication instead of passwords. From your host system, after you have password login working,

ssh-copy-id pi@<your hostname or IP>

If you want to disable password login edit /etc/sshd/sshd_config. And change,

PasswordAuthentication no

To pull an updated cgminer-klondike from the repo, and build,

cd cgminerklondike
git pull
make

The original commands used to configure cgminer and build were,

CFLAGS="g -O0 -W -Wall" ./autogen.sh –enableklondike
make
sudo make install

The default mining boot script uses “screen” to start a mining session that can be attached and detached from ssh as needed.

There is a bash alias set for attaching to the mining session,

alias mm='screen r Mining'
So simply typing mm<enter> will attach you, and Ctrl-A Ctrl-D will detach again.

Edit the ~/.cgminer/cgminer.conf file to suit your own pool server, or edit within cgminer and save the config. By default I have set my own donation server details and much appreciate any mining you happen to do for me.

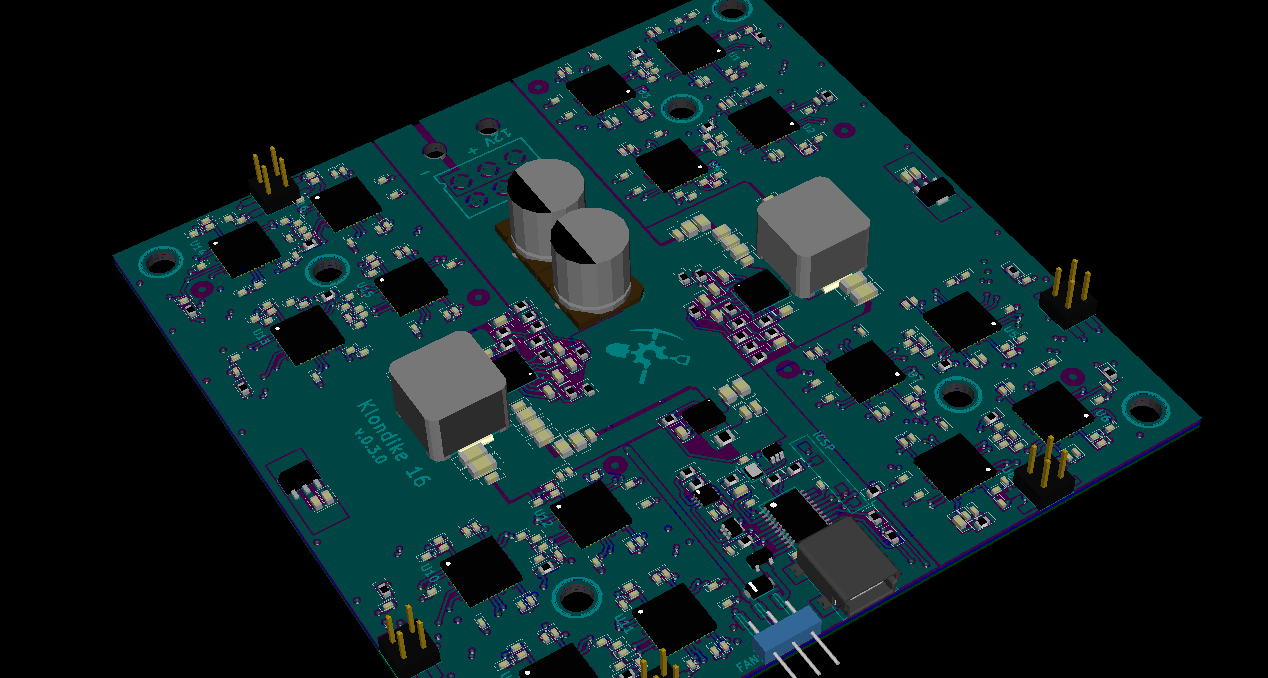
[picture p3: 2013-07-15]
docs/K16 3D.png

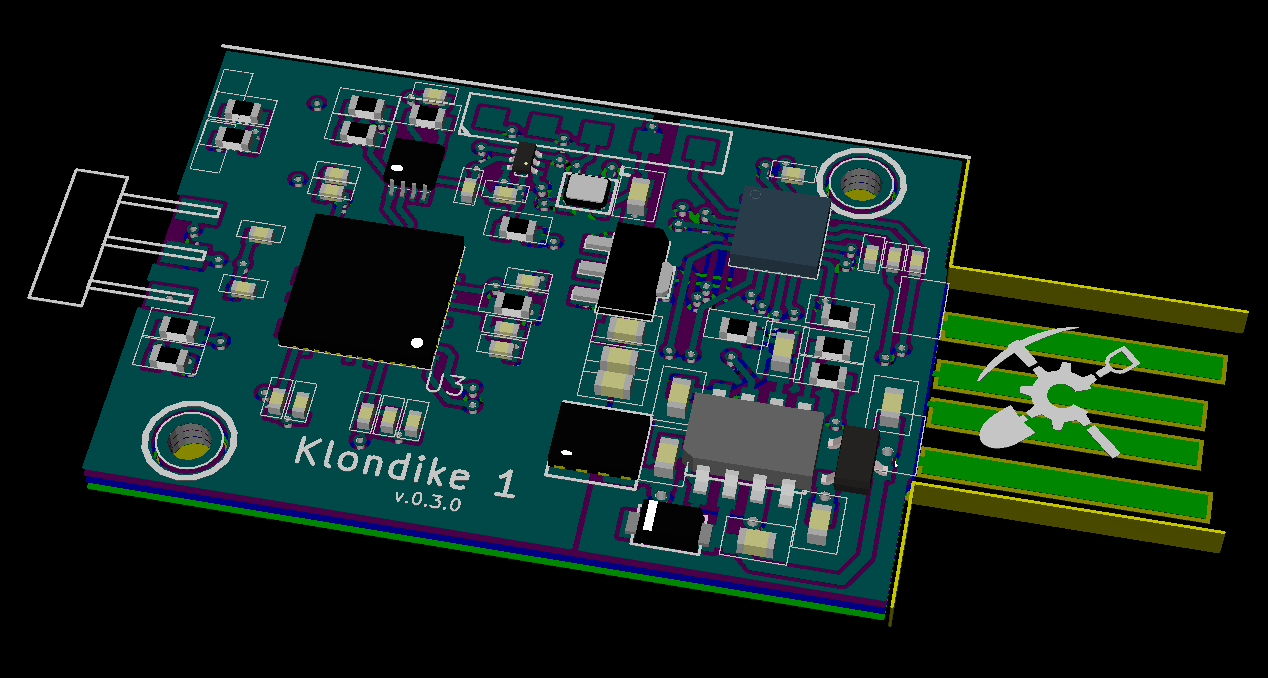
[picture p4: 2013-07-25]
docs/K1 Nano 3D.png

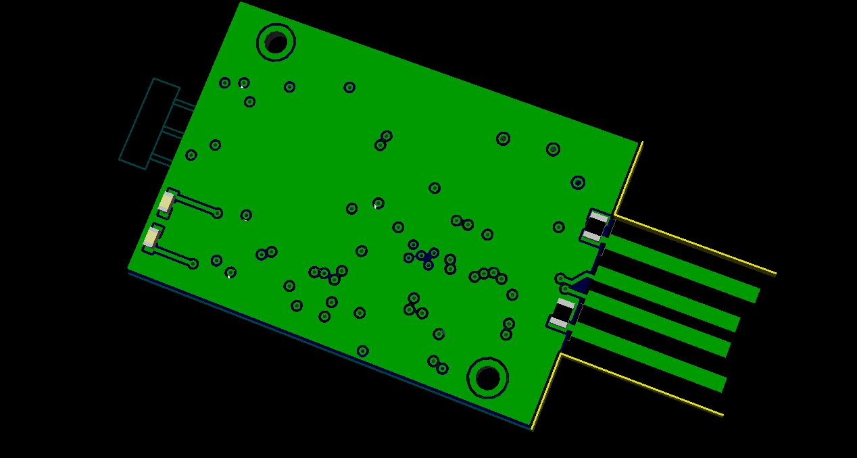
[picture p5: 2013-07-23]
docs/K1 Nano 3D Top.png

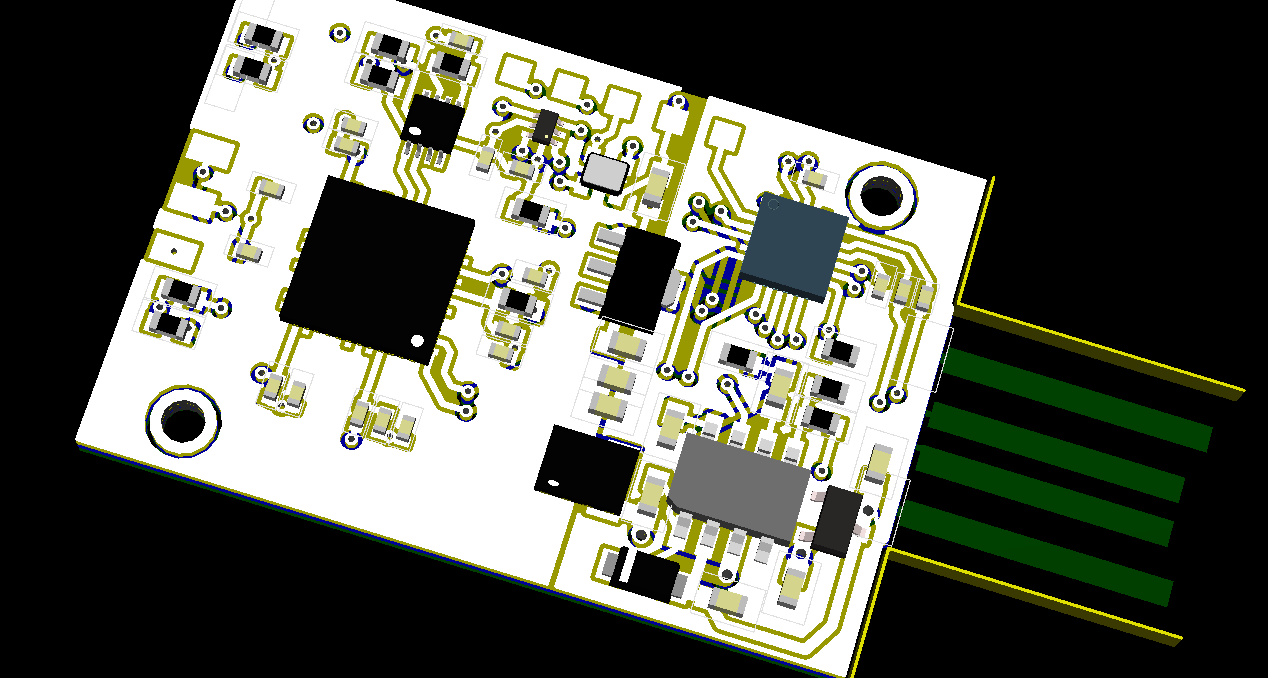
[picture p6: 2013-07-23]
docs/K1 Nano 3D White.png

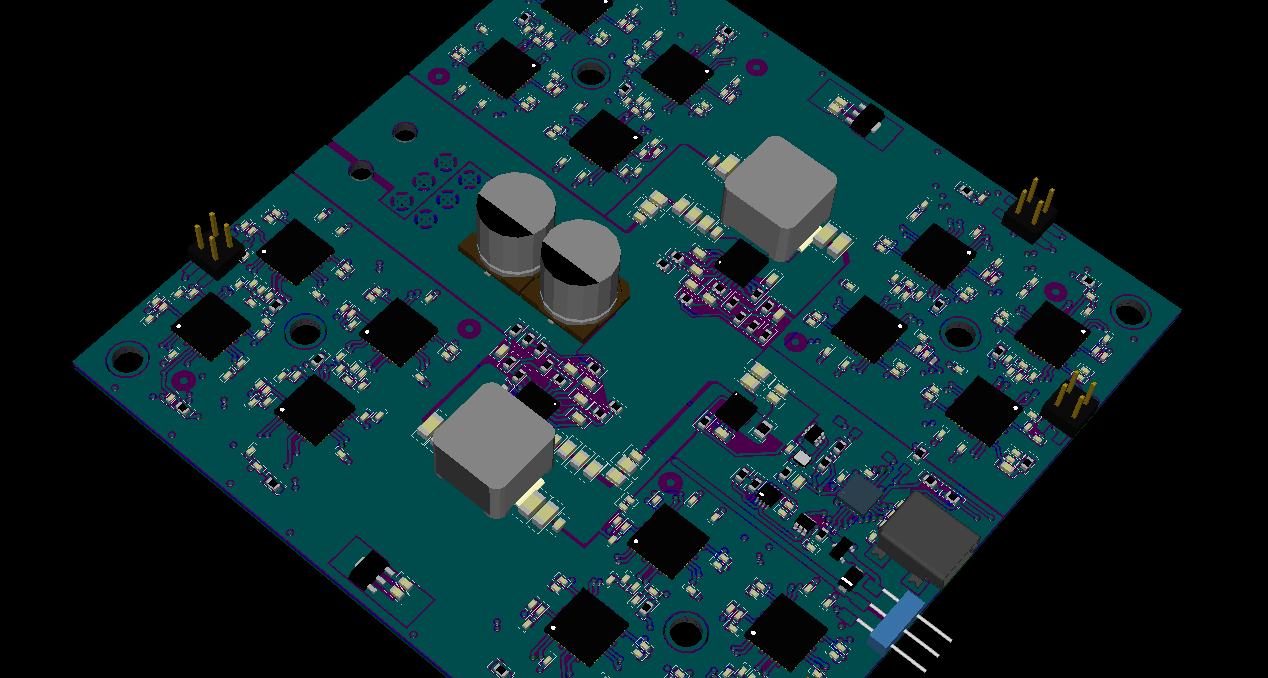
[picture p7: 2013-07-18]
docs/K16Q 3D.png

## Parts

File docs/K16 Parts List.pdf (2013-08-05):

## Klondike 16 – ASIC Miner Board

Part# | Description | Product # | MFR. | Value | Package | QTY | Qty 1 | Qty 25 | Qty 100 | Dist.
PCB | 4 Layer Circuit Board | PCB | China | 10cm x 10cm | | 1 | 9.000 | 5.000 | 2.700
U1-U16 | Avalon ASIC chip | AVALON | Avalon | | QFN48 | 16 | 0.000 | 0.000 | 0.000 | Avalon
U17 | USB Micro Controller | PIC16LF1459-I/SS | Microchip | | TSSOP-20 | 1 | 1.620 | 1.480 | 1.340 | Microchip
U17 | Alternate: USB Micro Controller | PIC16LF1459-I/ML | Microchip | | QFN20 | 0 | 1.660 | 1.520 | 1.380 | Microchip
U18-19 | 1.2V, 16A Buck Step Down Regulator | IR3895 | | 16A | PQFN-16 | 2 | 3.600 | 2.870 | 2.370 | Mouser
U20 | 3.3V, 1A Buck Step Down Regulator | MCP16321T-330E/NG | Microchip | 1A | VQFN-16 | 1 | 1.550 | 1.290 | 1.180 | Microchip
U21,U25 | Dual Schmitt Trigger Inverter | NL27WZ14DFT2G | On Semi. | | SOT-363 | 2 | 0.440 | 0.260 | 0.208 | Mouser
U22,U23 | 1.2V, 600mA LDO Regulator | AP7217D-12YG-13 | Diodes Inc. | 1.2V, 600mA | SOT-89-3L | 2 | 0.490 | 0.360 | 0.309
U24 | Dual NOR Gate | 74AUP2G02DC | NXP | | SOT-765-1 | 1 | 0.210 | 0.197 | 0.186 | Mouser
X1 | Oscillator | ASDMB-32.0-LC | | 32MHz | QFN4 | 1 | 1.690 | 1.430 | 1.010
Q1 | N-Channel MOSFET | NDS351AN | Fairchild | 1.4A, 30V | SSOT-3 | 1 | 0.230 | 0.199 | 0.171 | Mouser
D1 | Red LED (Data) | VLMS1300-GS08 | | 2V, 20mA | 0603 | 1 | 0.080 | 0.072 | 0.066 | Mouser
D2 | Green LED (Power) | VLMG1300-GS08 | | 2V, 20mA | 0603 | 1 | 0.080 | 0.076 | 0.070 | Mouser
D3 | | SL02-GS08 | | 1A, 30V | DO-219AB | 1 | 0.220 | 0.190 | 0.170 | Mouser
L1-2 | Power Inductor, Low DCR, 18A | 38L361C | | 0.360uH | 10x10 | 2 | 1.620 | 1.290 | 1.140 | Mouser
L3 | Power Inductor | MLP2016S4R7M | TDK | 4.7uH | 0806 | 1 | 0.290 | 0.273 | 0.236 | Mouser
L4-19 | Ferrite Bead Choke | ILBB0603ER600V | | 60 ohm, 25% | 0603 | 16 | 0.110 | 0.036 | 0.029 | Mouser
L20,L21 | Ferrite Bead Choke | BLM15BB121SN1D | | 120 ohm, 25% | 0402 | 2 | 0.240 | 0.105 | 0.060 | Mouser
L22,L23 | Ferrite Bead Choke | BLM15BB221SN1D | | 220 ohm, 25% | 0402 | 2 | 0.240 | 0.105 | 0.060 | Mouser
C19,C273 | Electrolytic Capacitor | UWT1V331MNL1GS | | 330uF | 10x10 | 2 | 0.165 | 0.132 | 0.132 | ES
C4-8,C23-27,C41,C42 | Ceramic Capacitor | GRM21BR61E106KA73L | | 10uF | 0805 | 12 | 0.218 | 0.179 | 0.130 | Mouser
C9-11,C28-30 | Ceramic Capacitor | GRM188R71E104KA01J | | 0.1uF | 0603 | 6 | 0.040 | 0.028 | 0.019 | Mouser
C3,C22 | Reference Capacitor | GRM1885C1H101JA01D | | 100pF | 0603 | 2 | 0.250 | 0.034 | 0.024 | Mouser
C16,C35 | Ceramic Capacitor | VJ0603Y332KXACW1BC | | 3300pF | 0603 | 2 | 0.060 | 0.050 | 0.040 | Mouser
C18,C37 | Ceramic Capacitor | VJ0603Y221MXJCW1BC | | 220pF | 0603 | 2 | 0.060 | 0.040 | 0.032 | Mouser
C12-15,C31-34 | Ceramic Capacitor | C3216X7S0J476M | TDK | 47uF | 1206 | 8 | 0.470 | 0.330 | 0.300 | Mouser
C2,C21 | Ceramic Capacitor | C1608X5R1V225M | TDK | 2.2uF | 0603 | 2 | 0.090 | 0.061 | 0.055 | Mouser
C17,C36 | Ceramic Capacitor | GRM188R71E103KA01J | | 10nF | 0603 | 2 | 0.200 | 0.027 | 0.018 | Mouser
C1,C20 | Ceramic Capacitor | GRM188R61E105KA12D | | 1.0uF | 0603 | 2 | 0.110 | 0.045 | 0.032 | Mouser
C38 | Ceramic Capacitor | VJ0603Y223KXACW1BC | | 22nF | 0603 | 1 | 0.080 | 0.060 | 0.050 | Mouser
C39,C40,C268-C271 | Ceramic Capacitor | C1608X5R0J226M | TDK | 22uF | 0603 | 6 | 0.150 | 0.117 | 0.106 | Mouser
C43-266 | Ceramic Capacitor | C1005X7S1A474K | TDK | 0.47uF | 0402 | 192 | 0.020 | 0.017 | 0.015 | Mouser
C272,C275 | Ceramic Capacitor | VJ0402Y103KXXAC | | 0.01uF | 0402 | 2 | 0.025 | 0.016 | 0.015 | Mouser
C274 | Ceramic Capacitor | GRM1555C1E300JA01D | | 30pF | 0402 | 1 | 0.250 | 0.034 | 0.024 | Mouser
C267,C276 | Ceramic Capacitor | GRM155R71C104KA88D | | 0.1uF | 0402 | 2 | 0.100 | 0.014 | 0.010 | Mouser
R8,R18 | Thick Film Resistor | ERJ-3EKF1781V | Panasonic | 1.78K 1% | 0603 | 2 | 0.070 | 0.020 | 0.003 | Mouser
R5,R9,R15,R19 | Thick Film Resistor | ERJ-3EKF4021V | Panasonic | 4.02K 1% | 0603 | 4 | 0.070 | 0.020 | 0.003 | Mouser
R7,R17,R10,R20 | Thick Film Resistor | ERJ-3EKF2871V | Panasonic | 2.87K 1% | 0603 | 4 | 0.070 | 0.020 | 0.003 | Mouser
R6,R16,R22,R43-44 | Thick Film Resistor | ERJ-3EKF1000V | Panasonic | 100 1% | 0603 | 5 | 0.070 | 0.020 | 0.003 | Mouser
R1,R11 | Thick Film Resistor | ERJ-3EKF3922V | Panasonic | 39.2K 1% | 0603 | 2 | 0.070 | 0.020 | 0.003 | Mouser
R3-4,R13-14 | Thick Film Resistor | ERJ-3EKF4992V | Panasonic | 49.9K 1% | 0603 | 4 | 0.070 | 0.020 | 0.003 | Mouser
R2,R12 | Thick Film Resistor | ERJ-3EKF7501V | Panasonic | 7.5K 1% | 0603 | 2 | 0.070 | 0.020 | 0.003 | Mouser
R21 | Thick Film Resistor | ERJ-3EKF1002V | Panasonic | 10K 1% | 0603 | 1 | 0.070 | 0.020 | 0.003 | Mouser
R23,R42,R45,R46,R48 | Thick Film Resistor | ERJ-3EKF1001V | Panasonic | 1K 1% | 0603 | 5 | 0.070 | 0.020 | 0.003 | Mouser
R24,R25 | Thick Film Resistor | ERJ-3EKF2201V | Panasonic | 2.2K 1% | 0603 | 2 | 0.070 | 0.020 | 0.003 | Mouser
R26-41 | Thick Film Resistor | ERJ-2RKF1003X | Panasonic | 100K | 0402 | 16 | 0.070 | 0.020 | 0.003 | Mouser
R47 | Thick Film Resistor | ERJ-2RKF1000X | Panasonic | 100 1% | 0402 | 1 | 0.070 | 0.020 | 0.003 | Mouser
RT1 | Thermistor | NCP15XW222J03RC | | 2.2K 5% | 0402 | 1 | 0.270 | 0.127 | 0.085 | Mouser
J1 | | 45718-0002 | | 6pin, 4.2mm | | 1 | 0.960 | 0.800 | 0.737 | Mouser
J1 | | 45558-0003 | | 6pin, 4.2mm | | 0 | 0.850 | 0.770 | 0.612 | Mouser
J1 | Alternate: Phoenix Terminal 2 pin | 1814634 or 1771091 | Phoenix | 6A, 2.5mm | SMD RA | 0 | 0.430 | 0.390 | 0.350 | Mouser
J2 | Mini USB Connector, Type B | 10033526-N3212MLF | FCI | 5pin | SMD | 1 | 0.450 | 0.430 | 0.390 | Mouser
J3,J5 | Pin Headers, SMD 4 pin Vertical | 14112 | 4UCONN | 2x2pin, 2.54mm | Vertical SMD | 4 | 0.089 | 0.089 | 0.089 | 4UCONN
J4 | Pin Header SMD, RA mount (FAN) | 11182 | 4UCONN | 3 pin, 2.54mm | RA SMD | 1 | 0.037 | 0.037 | 0.037 | 4UCONN
| | | | TOTAL | PER BOARD | 352 | 49.23 | 33.33 | 26.02
| | | | | SMD | 325
| | | | | QFN | 20
| | | | | Fine-Pitch | 1
| | | | | | 1
| | | | | Manual SMD | 5

Pricing was checked online but is a guide only and may not be accurate at the time of viewing.

Intl. Rect.

Digikey

Abracon | Digikey

Vishay
Vishay
Schottky Diode, Low Vf | Vishay

Murata

Vishay
Murata
Murata

Nichicon
Murata
Murata
Murata
Vishay
Vishay

Murata
Murata
Vishay

Vishay
Murata
Murata

Murata

Power Connector, MiniFitJr, PCIe | Molex | Thru-Hole
Alternate: Right Angle MiniFirJr, PCIe | Molex | Thru-Hole

Thru-Hole

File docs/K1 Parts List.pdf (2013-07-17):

Preliminary Parts List
| | | | | | | Cost | Cost | Cost
Part# | Description | Product # | MFR. | Value | Package | QTY | Qty 1 | Qty 25 | Qty 100 | Dist.
PCB | 4 Layer Circuit Board | PCB | China | 5cm x 2.5cm | | 1 | 2.500 | 0.900 | 0.600
U3 | Avalon ASIC chip | AVALON | Avalon | | QFN48 | 1 | 0.000 | 0.000 | 0.000 | Avalon
U2 | USB Micro Controller | PIC16LF1459-I/ML | Microchip | | QFN20 | 1 | 1.620 | 1.480 | 1.340 | Microchip
U1 | 1.2V, 2A Buck Step Down Regulator | AP6502A | Diodes Inc. | 2A | SOIC-8 | 1 | 0.930 | 0.728 | 0.351 | Mouser
U1 | Alternate: 1.2V, 3A Buck Reg | AP6503A | Diodes Inc. | 3A | SOIC-8 | 0 | 1.080 | 0.865 | 0.750 | Mouser
U4 | 3.3V, 250mA LDO Regulator | MCP1700T-3302E/TT | Microchip | 250mA | SOT-23 | 1 | 0.400 | 0.310 | 0.280 | Microchip
U4 | Alternate: AP7313-33 LDO Regulator | AP7313-33 | Diodes Inc. | 150mA | SOT-23R | 0 | 0.450 | 0.301 | 0.204 | Mouser
U5 | 1.2V, 600mA LDO Regulator | AP7217D-12YG-13 | Diodes Inc. | 600mA | SOT-89-3L | 1 | 0.490 | 0.360 | 0.309 | Mouser
U6 | Dual NOR Gate | 74AUP2G02DC | NXP | | SOT-765-1 | 1 | 0.210 | 0.197 | 0.186 | Mouser
U7 | Dual Schmitt Trigger Inverter | NL27WZ14DFT2G | On Semi. | | SOT-363 | 1 | 0.440 | 0.260 | 0.208 | Mouser
X1 | Oscillator | ASDMB-32.0-LC | | 32MHz | QFN4 | 1 | 1.690 | 1.430 | 1.010
D1 | | SL02-GS08 | | 1A, 30V | DO-219AB | 1 | 0.220 | 0.190 | 0.170 | Mouser
D2 | Red LED (Data) | VLMS1300-GS08 | | 2V, 20mA | 0603 | 1 | 0.080 | 0.072 | 0.066 | Mouser
D3 | Green LED (Power) | VLMG1300-GS08 | | 2V, 20mA | 0603 | 1 | 0.080 | 0.076 | 0.070 | Mouser
L1 | Power Inductor | SRN4018-3R3M | | 3.3uH, 2.2A | 4x4mm | 1 | 0.320 | 0.275 | 0.250 | Mouser
L1 | Alternate: Power Inductor | SRR6038-3R3Y | | 3.3uH, 3.5A | 6.8x6.8mm | 0 | 0.640 | 0.463 | 0.428 | Mouser
L2 | Ferrite Bead Choke | ILBB0603ER600V | | 60 ohm, 25% | 0603 | 1 | 0.110 | 0.036 | 0.029 | Mouser
L3,L4 | Ferrite Bead Choke | BLM15BB121SN1D | | 120 ohm, 300mA | 0402 | 2 | 0.240 | 0.105 | 0.060 | Mouser
L5,L6 | Ferrite Bead Choke | BLM21PG221SN1 | | 220 ohm, 2A | 0603 | 2 | 0.350 | 0.123 | 0.068 | Mouser
C1,C9-11 | Ceramic Capacitor | C1608X5R0J106M | TDK | 10uF | 0603 | 4 | 0.120 | 0.120 | 0.095 | Mouser
C2 | Ceramic Capacitor | GRM188R71E104KA01J | | 0.1uF | 0603 | 1 | 0.040 | 0.028 | 0.019 | Mouser
C4 | Ceramic Capacitor | VJ0603Y682KXXCW1BC | | 6.8nF | 0603 | 1 | 0.200 | 0.027 | 0.018 | Mouser
C5-6 | Ceramic Capacitor | C1608X5R0J226M | TDK | 22uF | 0603 | 2 | 0.150 | 0.117 | 0.106 | Mouser
C3,C7,C25 | Ceramic Capacitor | VJ0402Y103KXXAC | | 0.01uF | 0402 | 2 | 0.025 | 0.016 | 0.015 | Mouser
C12-23 | Ceramic Capacitor | C1005X7S1A474K | TDK | 0.47uF | 0402 | 12 | 0.020 | 0.017 | 0.015 | Mouser
C24 | Ceramic Capacitor | GRM1555C1E300JA01D | | 30pF | 0402 | 1 | 0.250 | 0.034 | 0.024 | Mouser
C8,C26 | Ceramic Capacitor | GRM155R71C104KA88D | | 0.1uF | 0402 | 2 | 0.100 | 0.014 | 0.010 | Mouser
R1 | Thick Film Resistor | ERJ-3EKF3001V | Panasonic | 3K | 0603 | 1 | 0.070 | 0.020 | 0.003 | Mouser
R2 | Thick Film Resistor | ERJ-3EKF1002V | Panasonic | 10K | 0603 | 1 | 0.070 | 0.020 | 0.003 | Mouser
R3 | Thick Film Resistor | ERJ-3EKF3241V | Panasonic | 3.24K | 0603 | 1 | 0.070 | 0.020 | 0.003 | Mouser
R4,R5,R9,R10,R12 | Thick Film Resistor | ERJ-3EKF1001V | Panasonic | 1K | 0603 | 5 | 0.070 | 0.020 | 0.003 | Mouser
R6 | Thick Film Resistor | ERJ-2RKF1003X | Panasonic | 100K | 0402 | 1 | 0.070 | 0.020 | 0.003 | Mouser
R7,R8,R11 | Thick Film Resistor | ERJ-3EKF1000V | Panasonic | 100 1% | 0603 | 3 | 0.070 | 0.020 | 0.003 | Mouser
RT1 | Thermistor | NCP15XW222J03RC | | 2.2K 5% | 0402 | 1 | 0.270 | 0.127 | 0.085 | Mouser
| | | | TOTAL | PER BOARD | 55 | 12.87 | 8.08 | 6.04

## Klondike 1 - Nano ASIC Miner

Pricing was checked online but is a guide only and may not be accurate at the time of viewing.

Abracon | Digikey
Schottky Diode, Low Vf | Vishay
Vishay
Vishay

Bourns
Bourns
Vishay
Murata
Murata

Murata
Vishay

Vishay

Murata
Murata

Murata

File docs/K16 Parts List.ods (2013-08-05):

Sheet: BOM
Klondike 16 – ASIC Miner Board
Pricing was checked online but is a guide only and may not be accurate at the time of viewing.
Part# | Description | Product # | MFR. | Value | Package | QTY | Qty 1 | Qty 25 | Qty 100 | Dist.
PCB | 4 Layer Circuit Board | PCB | China | 10cm x 10cm |  | 1 | 9.000 | 5.000 | 2.700
U1-U16 | Avalon ASIC chip | AVALON | Avalon |  | QFN48 | 16 | 0.000 | 0.000 | 0.000 | Avalon
U17 | USB Micro Controller | PIC16LF1459-I/SS | Microchip |  | TSSOP-20 | 1 | 1.620 | 1.480 | 1.340 | Microchip
U17 | Alternate: USB Micro Controller | PIC16LF1459-I/ML | Microchip |  | QFN20 | 0 | 1.660 | 1.520 | 1.380 | Microchip
U18-19 | 1.2V, 16A Buck Step Down Regulator | IR3895 | Intl. Rect. | 16A | PQFN-16 | 2 | 3.600 | 2.870 | 2.370 | Mouser
U20 | 3.3V, 1A Buck Step Down Regulator | MCP16321T-330E/NG | Microchip | 1A | VQFN-16 | 1 | 1.550 | 1.290 | 1.180 | Microchip
U21,U25 | Dual Schmitt Trigger Inverter | NL27WZ14DFT2G | On Semi. |  | SOT-363 | 2 | 0.440 | 0.260 | 0.208 | Mouser
U22,U23 | 1.2V, 600mA LDO Regulator | AP7217D-12YG-13 | Diodes Inc. | 1.2V, 600mA | SOT-89-3L | 2 | 0.490 | 0.360 | 0.309 | Digikey
U24 | Dual NOR Gate | 74AUP2G02DC | NXP |  | SOT-765-1 | 1 | 0.210 | 0.197 | 0.186 | Mouser
X1 | Oscillator | ASDMB-32.0-LC | Abracon | 32MHz | QFN4 | 1 | 1.690 | 1.430 | 1.010 | Digikey
Q1 | N-Channel MOSFET | NDS351AN | Fairchild | 1.4A, 30V | SSOT-3 | 1 | 0.230 | 0.199 | 0.171 | Mouser
D1 | Red LED (Data) | VLMS1300-GS08 | Vishay | 2V, 20mA | 0603 | 1 | 0.080 | 0.072 | 0.066 | Mouser
D2 | Green LED (Power) | VLMG1300-GS08 | Vishay | 2V, 20mA | 0603 | 1 | 0.080 | 0.076 | 0.070 | Mouser
D3 | Schottky Diode, Low Vf | SL02-GS08 | Vishay | 1A, 30V | DO-219AB | 1 | 0.220 | 0.190 | 0.170 | Mouser
L1-2 | Power Inductor, Low DCR, 18A | 38L361C | Murata | 0.360uH | 10x10 | 2 | 1.620 | 1.290 | 1.140 | Mouser
L3 | Power Inductor | MLP2016S4R7M | TDK | 4.7uH | 0806 | 1 | 0.290 | 0.273 | 0.236 | Mouser
L4-19 | Ferrite Bead Choke | ILBB0603ER600V | Vishay | 60 ohm, 25% | 0603 | 16 | 0.110 | 0.036 | 0.029 | Mouser
L20,L21 | Ferrite Bead Choke | BLM15BB121SN1D | Murata | 120 ohm, 25% | 0402 | 2 | 0.240 | 0.105 | 0.060 | Mouser
L22,L23 | Ferrite Bead Choke | BLM15BB221SN1D | Murata | 220 ohm, 25% | 0402 | 2 | 0.240 | 0.105 | 0.060 | Mouser
C19,C273 | Electrolytic Capacitor | UWT1V331MNL1GS | Nichicon | 330uF | 10x10 | 2 | 0.165 | 0.132 | 0.132 | ES
C4-8,C23-27,C41,C42 | Ceramic Capacitor | GRM21BR61E106KA73L | Murata | 10uF | 0805 | 12 | 0.218 | 0.179 | 0.130 | Mouser
C9-11,C28-30 | Ceramic Capacitor | GRM188R71E104KA01J | Murata | 0.1uF | 0603 | 6 | 0.040 | 0.028 | 0.019 | Mouser
C3,C22 | Reference Capacitor | GRM1885C1H101JA01D | Murata | 100pF | 0603 | 2 | 0.250 | 0.034 | 0.024 | Mouser
C16,C35 | Ceramic Capacitor | VJ0603Y332KXACW1BC | Vishay | 3300pF | 0603 | 2 | 0.060 | 0.050 | 0.040 | Mouser
C18,C37 | Ceramic Capacitor | VJ0603Y221MXJCW1BC | Vishay | 220pF | 0603 | 2 | 0.060 | 0.040 | 0.032 | Mouser
C12-15,C31-34 | Ceramic Capacitor | C3216X7S0J476M | TDK | 47uF | 1206 | 8 | 0.470 | 0.330 | 0.300 | Mouser
C2,C21 | Ceramic Capacitor | C1608X5R1V225M | TDK | 2.2uF | 0603 | 2 | 0.090 | 0.061 | 0.055 | Mouser
C17,C36 | Ceramic Capacitor | GRM188R71E103KA01J | Murata | 10nF | 0603 | 2 | 0.200 | 0.027 | 0.018 | Mouser
C1,C20 | Ceramic Capacitor | GRM188R61E105KA12D | Murata | 1.0uF | 0603 | 2 | 0.110 | 0.045 | 0.032 | Mouser
C38 | Ceramic Capacitor | VJ0603Y223KXACW1BC | Vishay | 22nF | 0603 | 1 | 0.080 | 0.060 | 0.050 | Mouser
C39,C40,C268-C271 | Ceramic Capacitor | C1608X5R0J226M | TDK | 22uF | 0603 | 6 | 0.150 | 0.117 | 0.106 | Mouser
C43-266 | Ceramic Capacitor | C1005X7S1A474K | TDK | 0.47uF | 0402 | 192 | 0.020 | 0.017 | 0.015 | Mouser
C272,C275 | Ceramic Capacitor | VJ0402Y103KXXAC | Vishay | 0.01uF | 0402 | 2 | 0.025 | 0.016 | 0.015 | Mouser
C274 | Ceramic Capacitor | GRM1555C1E300JA01D | Murata | 30pF | 0402 | 1 | 0.250 | 0.034 | 0.024 | Mouser
C267,C276 | Ceramic Capacitor | GRM155R71C104KA88D | Murata | 0.1uF | 0402 | 2 | 0.100 | 0.014 | 0.010 | Mouser
R8,R18 | Thick Film Resistor | ERJ-3EKF1781V | Panasonic | 1.78K 1% | 0603 | 2 | 0.070 | 0.020 | 0.003 | Mouser
R5,R9,R15,R19 | Thick Film Resistor | ERJ-3EKF4021V | Panasonic | 4.02K 1% | 0603 | 4 | 0.070 | 0.020 | 0.003 | Mouser
R7,R17,R10,R20 | Thick Film Resistor | ERJ-3EKF2871V | Panasonic | 2.87K 1% | 0603 | 4 | 0.070 | 0.020 | 0.003 | Mouser
R6,R16,R22,R43-44 | Thick Film Resistor | ERJ-3EKF1000V | Panasonic | 100 1% | 0603 | 5 | 0.070 | 0.020 | 0.003 | Mouser
R1,R11 | Thick Film Resistor | ERJ-3EKF3922V | Panasonic | 39.2K 1% | 0603 | 2 | 0.070 | 0.020 | 0.003 | Mouser
R3-4,R13-14 | Thick Film Resistor | ERJ-3EKF4992V | Panasonic | 49.9K 1% | 0603 | 4 | 0.070 | 0.020 | 0.003 | Mouser
R2,R12 | Thick Film Resistor | ERJ-3EKF7501V | Panasonic | 7.5K 1% | 0603 | 2 | 0.070 | 0.020 | 0.003 | Mouser
R21 | Thick Film Resistor | ERJ-3EKF1002V | Panasonic | 10K 1% | 0603 | 1 | 0.070 | 0.020 | 0.003 | Mouser
R23,R42,R45,R46,R48 | Thick Film Resistor | ERJ-3EKF1001V | Panasonic | 1K 1% | 0603 | 5 | 0.070 | 0.020 | 0.003 | Mouser
R24,R25 | Thick Film Resistor | ERJ-3EKF2201V | Panasonic | 2.2K 1% | 0603 | 2 | 0.070 | 0.020 | 0.003 | Mouser
R26-41 | Thick Film Resistor | ERJ-2RKF1003X | Panasonic | 100K | 0402 | 16 | 0.070 | 0.020 | 0.003 | Mouser
R47 | Thick Film Resistor | ERJ-2RKF1000X | Panasonic | 100 1% | 0402 | 1 | 0.070 | 0.020 | 0.003 | Mouser
RT1 | Thermistor | NCP15XW222J03RC | Murata | 2.2K 5% | 0402 | 1 | 0.270 | 0.127 | 0.085 | Mouser
J1 | Power Connector, MiniFitJr, PCIe | 45718-0002 | Molex | 6pin, 4.2mm | Thru-Hole | 1 | 0.960 | 0.800 | 0.737 | Mouser
J1 | Alternate: Right Angle MiniFirJr, PCIe | 45558-0003 | Molex | 6pin, 4.2mm | Thru-Hole | 0 | 0.850 | 0.770 | 0.612 | Mouser
J1 | Alternate: Phoenix Terminal 2 pin | 1814634 or 1771091 | Phoenix | 6A, 2.5mm | SMD RA | 0 | 0.430 | 0.390 | 0.350 | Mouser
J2 | Mini USB Connector, Type B | 10033526-N3212MLF | FCI | 5pin | SMD | 1 | 0.450 | 0.430 | 0.390 | Mouser
J3,J5 | Pin Headers, SMD 4 pin Vertical | 14112 | 4UCONN | 2x2pin, 2.54mm | Vertical SMD | 4 | 0.089 | 0.089 | 0.089 | 4UCONN
J4 | Pin Header SMD, RA mount (FAN) | 11182 | 4UCONN | 3 pin, 2.54mm | RA SMD | 1 | 0.037 | 0.037 | 0.037 | 4UCONN
 |  |  |  | TOTAL | PER BOARD | 352 | 49.23 | 33.33 | 26.02
 |  |  |  |  | SMD | 325
 |  |  |  |  | QFN | 20
 |  |  |  |  | Fine-Pitch | 1
 |  |  |  |  | Thru-Hole | 1
 |  |  |  |  | Manual SMD | 5

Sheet: Footprints
Klondike 16 – ASIC Miner Board
 |  |  |  | K16 | Datasheet
Part# | Description | Product # | Package | Library | Re-Verified
U1-U16 | Avalon ASIC chip | AVALON | QFN48 | QFN48 | Y
U17 | USB Micro Controller | PIC16LF1459-I/SS | TSSOP-20 | SSOP20 | Y
U17 | Alternate: USB Micro Controller | PIC16LF1459-I/ML | QFN20 | PIC16LF1459-ML | Y
U18-19 | 1.2V, 16A Buck Step Down Regulator | IR3895 | PQFN-16 | PQFN-16 | Y
U20 | 3.3V, 1A Buck Step Down Regulator | MCP16321T-330E/NG | VQFN-16 | QFN16 | Y
U21,U25 | Dual Schmitt Trigger Inverter | NL27WZ14DFT2G | SOT-363 | SOT-363 | Y
U22,U23 | 1.2V, 600mA LDO Regulator | AP7217D-12YG-13 | SOT-89-3L | SOT89-3L | Y
U24 | Dual NOR Gate | 74AUP2G02DC | SOT-765-1 | SOT765-1 | Y
X1 | Oscillator | ASDMB-32.0-LC | QFN4 | QFN48 | Y
Q1 | N-Channel MOSFET | NDS351AN | SSOT-3 | SSOT-3L | Y
D1 | Red LED (Data) | VLMS1300-GS08 | 0603 | D0603 | Y
D2 | Green LED (Power) | VLMG1300-GS08 | 0603 | D0603 | Y
D3 | Schottky Diode, Low Vf | SL02-GS08 | DO-219AB | DO219AB | Y
L1-2 | Power Inductor, Low DCR, 18A | 38L361C | 10x10 | 38L361C | Y
L3 | Power Inductor | MLP2016S4R7M | 0806 | L0805 | Y
L4-19 | Ferrite Bead Choke | ILBB0603ER600V | 0603 | L0603 | Y
L20,L21 | Ferrite Bead Choke | BLM15BB121SN1D | 402 | L0402 | Y
L22,L23 | Ferrite Bead Choke | BLM15BB221SN1D | 402 | L0402 | Y
C19,C273 | Electrolytic Capacitor | UWT1V331MNL1GS | 10x10 | Nichicon-10mm | Y
C4-8,C23-27,C41,C42 | Ceramic Capacitor | GRM21BR61E106KA73L | 0805 | C0805 | Y
C9-11,C28-30 | Ceramic Capacitor | GRM188R71E104KA01J | 0603 | C0603 | Y
C3,C22 | Reference Capacitor | GRM1885C1H101JA01D | 0603 | C0603 | Y
C16,C35 | Ceramic Capacitor | VJ0603Y332KXACW1BC | 0603 | C0603 | Y
C18,C37 | Ceramic Capacitor | VJ0603Y221MXJCW1BC | 0603 | C0603 | Y
C12-15,C31-34 | Ceramic Capacitor | C3216X7S0J476M | 1206 | C1206 | Y
C2,C21 | Ceramic Capacitor | C1608X5R1V225M | 0603 | C0603 | Y
C17,C36 | Ceramic Capacitor | GRM188R71E103KA01J | 0603 | C0603 | Y
C1,C20 | Ceramic Capacitor | GRM188R61E105KA12D | 0603 | C0603 | Y
C38 | Ceramic Capacitor | VJ0603Y223KXACW1BC | 0603 | C0603 | Y
C39,C40,C268-C271 | Ceramic Capacitor | C1608X5R0J226M | 0603 | C0603 | Y
C43-266 | Ceramic Capacitor | C1005X7S1A474K | 0402 | C0402 | Y
C272,C275 | Ceramic Capacitor | VJ0402Y103KXXAC | 0402 | C0402 | Y
C274 | Ceramic Capacitor | GRM1555C1E300JA01D | 0402 | C0402 | Y
C267,C276 | Ceramic Capacitor | GRM155R71C104KA88D | 0402 | C0402 | Y
R8,R18 | Thick Film Resistor | ERJ-3EKF1781V | 0603 | R0603 | Y
R5,R9,R15,R19 | Thick Film Resistor | ERJ-3EKF4021V | 0603 | R0603 | Y
R7,R17,R10,R20 | Thick Film Resistor | ERJ-3EKF2871V | 0603 | R0603 | Y
R6,R16,R22,R43-44,R47 | Thick Film Resistor | ERJ-3EKF1000V | 0603 | R0603 | Y
R1,R11 | Thick Film Resistor | ERJ-3EKF3922V | 0603 | R0603 | Y
R3-4,R13-14 | Thick Film Resistor | ERJ-3EKF4992V | 0603 | R0603 | Y
R2,R12 | Thick Film Resistor | ERJ-3EKF7501V | 0603 | R0603 | Y
R21 | Thick Film Resistor | ERJ-3EKF1002V | 0603 | R0603 | Y
R23,R42,R45,R46,R48 | Thick Film Resistor | ERJ-3EKF1001V | 0603 | R0603 | Y
R24,R25 | Thick Film Resistor | ERJ-3EKF2201V | 0603 | R0603 | Y
R26-41 | Thick Film Resistor | ERJ-2RKF1003X | 0402 | R0402 | Y
RT | Thermistor | NCP15XW222J03RC | 0402 | R0402 | Y
J1 | Power Connector, MiniFitJr, PCIe | 45718-0002 | Thru-Hole
J1 | Alternate: Right Angle MiniFirJr, PCIe | 45558-0003 | Thru-Hole
J1 | Alternate: Phoenix Terminal 2 pin | 1814634 or 1771091 | SMD RA
J2 | Mini USB Connector, Type B | 10033526-N3212MLF | SMD
J3,J5 | Pin Headers, SMD 4 pin Vertical | 14112 | Vertical SMD
J4 | Pin Header SMD, RA mount (FAN) | 11182 | RA SMD

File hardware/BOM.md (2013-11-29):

Open Source Bitcoin Miner  Revised: Tuesday, November 05, 2013
Drawn By: George Hahn          Revision: A

Bill Of Materials       November 12,2013      23:07:57	Page1

Item	Quantity	Reference	Part
______________________________________________

1.	[*330uF	cap_2917* **2x	C1,C2**](http://www.digikey.com/product-search/en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)
2.	[*22uF	cap_0603* **1x	C3**](http://www.digikey.com/product-detail/en/C1608X5R0J226M080AC/445-8028-1-ND/2792158)
3.	[*1200pF	cap_0603* **2x	C4,C5**](http://www.digikey.com/product-detail/en/GRM188R72A122KA01D/490-1474-1-ND/587849)
4.	[*0.1uF	cap_0603* **1x	C6**](http://www.digikey.com/product-detail/en/C1608X7R1H104K080AA/445-1314-1-ND/567687)
5.	[*0.022uF	cap_0603* **1x	C7**](http://www.digikey.com/product-detail/en/C1608X7R1H223K080AA/445-1312-1-ND/567696)
6.	[*1uF	cap_0603* **2x	C8,C9**](http://www.digikey.com/product-detail/en/TMK107BJ105KA-T/587-1248-1-ND/931025)
7.	[*4.7uF	cap_1206* **4x	C10,C11,C12,C13**](http://www.digikey.com/product-detail/en/C3216X5R1E475K115AB/445-14683-1-ND/3956349)
8.	[*22uF	cap_1206* **22x	C14,C15,C16,C17,C18,C19,
			C20,C21,C22,C23,C24,C25,
			C26,C27,C28,C29,C30,C31,
			C32,C33,C34,C35**](http://www.digikey.com/product-search/en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)
9.	[*0.01uF	cap_0603* **6x	C36,C38,C40,C42,C44,C46**](http://www.digikey.com/product-detail/en/CL10B103KB8NCNC/1276-1921-1-ND/3890007)
10.	[*4.7uF	cap_0603* **5x	C37,C39,C41,C43,C45**](http://www.digikey.com/product-detail/en/CL10B475KQ8NQNC/1276-2087-1-ND/3890173)
11.	[*0.47uF	cap_0603* **120x	C47,C48,C49,C50,C51,C52,
			C53,C54,C55,C56,C57,C58,
			C59,C60,C61,C62,C63,C64,
			C65,C66,C67,C68,C69,C70,
			C71,C72,C73,C74,C75,C76,
			C77,C78,C79,C80,C81,C82,
			C83,C84,C85,C86,C87,C88,
			C89,C90,C91,C92,C93,C94,
			C95,C96,C97,C98,C99,C100,
			C101,C102,C103,C104,C105,
			C106,C107,C108,C109,C110,
			C111,C112,C113,C114,C115,
			C116,C117,C118,C119,C120,
			C121,C122,C123,C124,C125,
			C126,C127,C128,C129,C130,
			C131,C132,C133,C134,C135,
			C136,C137,C138,C139,C140,
			C141,C142,C143,C144,C145,
			C146,C147,C148,C149,C150,
			C151,C152,C153,C154,C155,
			C156,C157,C158,C159,C160,
			C161,C162,C163,C164,C165,
			C166**](http://www.digikey.com/product-detail/en/CC0603KRX7R8BB473/311-1373-1-ND/2103157)
12.	[*30pF	cap_0603* **1x	C167**](http://www.digikey.com/product-detail/en/CL10C300JB8NNNC/1276-1021-1-ND/3889107)
13.	*XuF	cap_0603* **2x	C168,C169**
14.	[*CMDSH-3	SOD323* **1x	D1**](http://www.digikey.com/product-search/en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)
15.	[*LED	apa3010srcprv-gx* **4x	D2,D3,D4,D5**](http://www.digikey.com/product-search/en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)
16.	*Drill - Unplated M3	Part_drill_m3_33000mm* **4x	H1,H2,H3,H4**
17.	[*CUI PJ-037BH	CUI_PJ_037BH* **1x	J1**](http://www.digikey.com/product-search/en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)
18.	*ICSP	HEADER100_5* **1x	J2**
19.	[*Molex 0473460001	Molex_0473460001* **1x	J3**](http://www.digikey.com/product-search/en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)
20.	*FAN	header100_3* **1x	J4**
21.	[*560nH	ETQ-P4L* **1x	L1**](http://www.digikey.com/product-search/en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)
22.	[*BLM18HE102SN1D	ind_0603* **13x	L2,L3,L4,L5,L6,L7,L8,L9,
			L10,L11,L12,L13,L14**](http://www.digikey.com/product-search/en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)
23.	[*BC817-25-7-F	sot23* **1x	Q1**](http://www.digikey.com/product-search/en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)
24.	[*10	res_0805* **1x	R1**](http://www.digikey.com/product-detail/en/RMCF0805JT10R0/RMCF0805JT10R0CT-ND/1942532)
25.	[*0	res_0603* **2x	R2,R4**](http://www.digikey.com/product-detail/en/RMCF0603ZT0R00/RMCF0603ZT0R00CT-ND/1943218)
26.	[*5.11k	res_0603* **2x	R3,R5**](http://www.digikey.com/product-detail/en/RMCF0603FT5K11/RMCF0603FT5K11CT-ND/1943038)
28.	[*1.21k	res_0603* **1x	R6**](http://www.digikey.com/product-detail/en/RMCF0603FT1K21/RMCF0603FT1K21CT-ND/1943000)
29.	[*100k	res_0603* **11x	R7,R17,R18,R19,R20,R21,
			R22,R23,R24,R25,R26**](http://www.digikey.com/product-detail/en/RMCF0603JT100K/RMCF0603JT100KCT-ND/1943203)
30.	[*0.003	res_1225* **1x	R9**](http://www.digikey.com/product-search/en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)
31.	[*182	res_0603* **1x	R10**](http://www.digikey.com/product-detail/en/RMCF0603FT182R/RMCF0603FT182RCT-ND/2417953)
32.	[*100	res_0603* **2x	R11,R29**](http://www.digikey.com/product-detail/en/RMCF0603JT100R/RMCF0603JT100RCT-ND/1943156)
33.	[*2.2	res_0805* **1x	R12**](http://www.digikey.com/product-detail/en/RMCF0603JT2R20/RMCF0603JT2R20CT-ND/2418194)
34.	[*75-100	res_0603* **4x	R13,R14,R15,R16**](http://www.digikey.com/product-detail/en/RMCF0603JT100R/RMCF0603JT100RCT-ND/1943156)
35.	[*1k	res_0603* **2x	R27,R28**](http://www.digikey.com/product-detail/en/RMCF0603JT1K00/RMCF0603JT1K00CT-ND/1943173)
36.	[*40k	res_0603* **1x	R30**](http://www.digikey.com/product-detail/en/RMCF0603FT40K2/RMCF0603FT40K2CT-ND/1943095)
37.	[*1k, 1/4W	res_1206* **1x	R31**](http://www.digikey.com/product-detail/en/RMCF1206JT1K00/RMCF1206JT1K00CT-ND/1942786)
38.	[*13k	res_0603* **1x	R32**](http://www.digikey.com/product-detail/en/RMCF0603FT13K0/RMCF0603FT13K0CT-ND/1943065)
39.	[*10k	res_0603* **1x	R33**](http://www.digikey.com/product-detail/en/RMCF0603JT10K0/RMCF0603JT10K0CT-ND/1943191)
40.	[*10	res_0603* **1x	R34**](http://www.digikey.com/product-detail/en/RMCF0603JT10R0/RMCF0603JT10R0CT-ND/1943148)
41.	[*470	res_0603* **1x	R35**](http://www.digikey.com/product-detail/en/RMCF0603JT470R/RMCF0603JT470RCT-ND/1943166)
42.	[*LM27213	DGG* **1x	U1**](http://www.digikey.com/product-detail/en/LM27213MTD%2FNOPB/LM27213MTD%2FNOPB-ND/1871068)
43.	[*AP1117IE33G-13	sot224* **1x	U3**](http://www.digikey.com/product-search/en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)
44.	[*KA78L05AIDTF	8-soic* **1x	U4**](http://www.digikey.com/product-search/en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)
45.	[*IDT74FCT3807APYG	20-ssop* **1x	U5**](http://www.digikey.com/product-search/en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)
46.	[*ASDMB-25.000MHz	4-smd-dfnllc* **1x	U6**](http://www.digikey.com/product-detail/en/ASDMB-25.000MHZ-LC-T/535-11730-1-ND/2809943)
47.	[*PIC18F45K50	40-ufqfn* **1x	U7**](http://www.digikey.com/product-detail/en/PIC18F45K50-I%2FMV/PIC18F45K50-I%2FMV-ND/3671504)
48.	*BitSyncom A3255Q48	QFN48* **10x	U8,U9,U10,U11,U12,U13,
			U14,U15,U16,U17**
49.	[*74AUP2G02GF,115	8-xson* **1x	U18**](http://www.digikey.com/product-search/en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)
50.	[*NL27WZ14DFT2G	sc-88* **1x	U19**](http://www.digikey.com/product-search/en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)
51.	[*LM63	TI_D_R_PDSO_G8* **1x	U20**](http://www.digikey.com/product-detail/en/LM63CIMAX%2FNOPB/LM63CIMAX%2FNOPBCT-ND/3527023)
52.	[*CSD86350Q5D	QFN127P600X500X150-9N* **1x	U21**](http://www.digikey.com/product-search/en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)
53.	[*CRYSTAL	hc49_us* **1x	Y1**](http://www.digikey.com/product-search/en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)

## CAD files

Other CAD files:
firmware/Klondike.X/dist/K16/production/Klondike.X.production.obj
firmware/Klondike.X/l.obj
hardware/footprints/Footprint Library/20-SSOP.psm
hardware/footprints/Footprint Library/4-SMD-DFNLLC.psm
hardware/footprints/Footprint Library/40-UFQFN.psm
hardware/footprints/Footprint Library/8-SOIC.psm
hardware/footprints/Footprint Library/8-XSON.psm
hardware/footprints/Footprint Library/CRYSTAL1110X360N_Allegro/HC49_US.psm
hardware/footprints/Footprint Library/DFN250X135X312-4N_Allegro/4-SMD-DFNLLC.psm
hardware/footprints/Footprint Library/HC49_US.psm
hardware/footprints/Footprint Library/MOLEX/molex_0473460001.psm
hardware/footprints/Footprint Library/QFN127P600X500X150-9N_Allegro/8SON_POWERBLOCK.psm
hardware/footprints/Footprint Library/QFN127P600X500X150-9N_Allegro/qfn127p600x500x150-9n.psm
hardware/footprints/Footprint Library/QFN40P500X500X80-41N_Allegro/qfn40p500x500x80-41n.psm
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

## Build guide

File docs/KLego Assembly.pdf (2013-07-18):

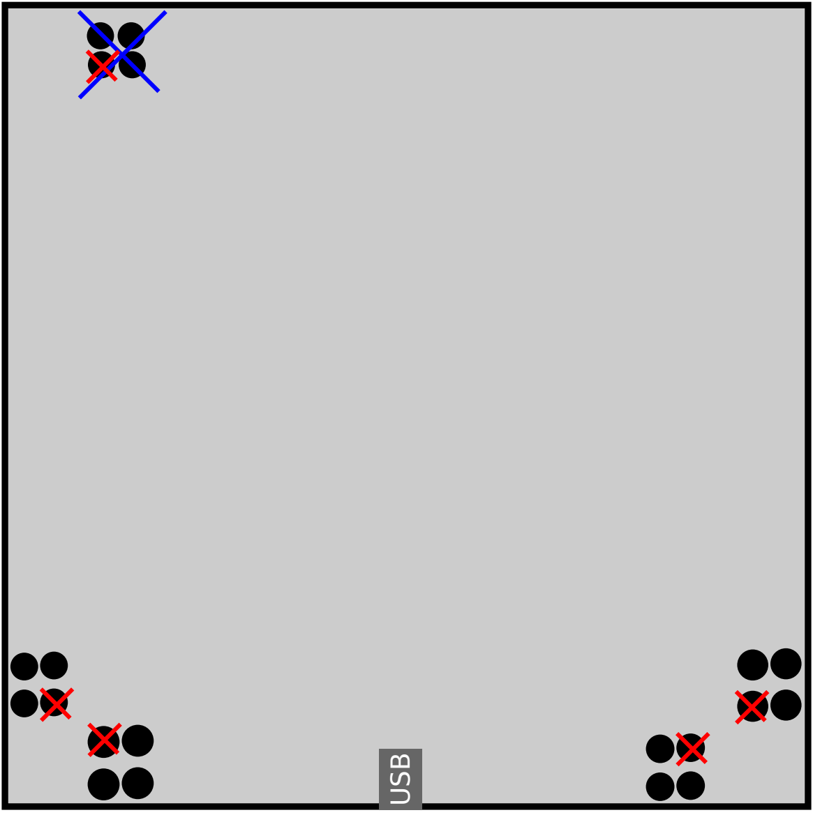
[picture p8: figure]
USB

Remove VCC pin as key to ensure cables are attached correctly. The VCC pin is only used
when a special "repeater" klego bar is attached to extend bus length. Not available at this time.

Optional pin header - not recommended but can be used for Front-Back tiling
on slaves when the USB is not required.

# KLego Assembly Drawing

Klondike boards can be tiled to form larger arrays. Recommended pattern is Side-Side tiling but connectors are installed on the front and back for Front-Front and Front-Back tiling.

Front-Front tiling is only suitable for slaves where the USB port is unused.

Front-Back tiling requires using a vertical power connector since the USB connector blocks power connection on the second board. For this reason it's marked as optional.

Front-Side or Back-Side tiling is not recommended due to heat sink fins not aligning which would result in poor air flow. This could be used for water cooled arrays, or with heat sinks having pins instead of fins.

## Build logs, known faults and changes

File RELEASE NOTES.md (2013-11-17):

# Release Notes

### November 4, 2013 - Avalon Board Original Release - Alpha

 - Designed on Upverter, copied to Cadence OrCAD + Allegro for initial design. The entire design will be backported to Upverter once their module system has stabilized.
 - Four layer board, 3.36x3.25in

# Klondike Release Notes

### July 23, 2013 - K1 Board Revised - v0.3.0 - Final Beta

The "Final Beta" Revision of K1 has been pushed up to GitHub.

- **Added Dual NOR gate and Inverters from testing on K16 to improve result capture.**
- Changed PIC to use QFN version.
- **Added 2mm holes for fastening heat sink.**
- Made both LEDs flashable under software control for better blinkies.
- **Added thermistor for sensing temperature.**
- **Added another PIC decoupling capacitor.**
- **Fixed issues with buck regulator traces.**
- I2C chain conn. now non-thru hole pads - fits 3 pin header.
- **Added ferrite beads to ASIC power and USB signals.**

### July 15, 2013 - K16 Board Revised - v0.3.0 - Final testing

- **Dual NOR gate replaces Single NOR gate**
- **Inverters added before PIC on result data, clk**
- **Schottky Diode added across Fan terminals**
- **1K resistor added to pull down FET gate**
- **Ferrite beads added to AVDD on ASIC PLL supply**
- **Ferrite beads added to USB D+/D-/GND and shield to GND**
- **moved PIC decoupling capacitor to be closer to PIC**
- **added 2 more decoupling capacitors near PIC and inverters**
- added NPTh for PICe connector to support horizontal version
- Phoenix 2 pin power connector removed
- new logo added (thanks Laserhorse!)
- **moved thermistor to between U7,U8**
- moved large input capacitors a little for better PCIe clearance
- small edits to clean up traces here and there
- repositioned a few parts
- footprints verified and updated against data sheets

### June 14, 2013 - Original Release - 0.1.0

The kicad files originated from Eagle CAD files through a conversion. This has caused some weird side effects that make the schematic a nuisance to work with. The parts co-ordinates were placed on a 1 mil grid during conversion making them both very small and very difficult to edit. You must always choose the 1 mil grid option if you hope to do any editing of the wires and parts and even then it's difficult. 

My recommendation: if you ever find yourself using Eagle and wanting to use Kicad - start over fresh, do not convert. I would not have used less than a 10 mil grid and would have used several pages instead of one large one. But here it is, painful glory, and all. I planned to revamp it all later, and maybe that will get done but not in time for this rushed initial release.

One part is known to be missing here from the original Avalon design. That is the ferrite beads on the AVDD power line to each chip. This was missed by me when viewing the Avalon reference docs and the first version of the PCB does not have them. So we'll see if they are absolutely required, or just precautionary niceties to ensure better EMI behaviour.

The Klondike firmware was developed using Microchips MPLAB-X IDE 1.7 under Ubuntu 12.04 (Linux) with the XC-8 Compiler 1.12, PRO trial mode enabled.

It cannot be compiled in FREE mode as, with super-lousy code generation and the massive bloat it creates, it will not fit in the 8K code space available.

At the time of current testing, incomplete, the code uses 5595 code space (8192 max) and 816 data space (1024 max).

The ktest utility is very rudimentary but provides a way to feed the klondike until a driver for cgminer is written. It will be enhanced to allow feeding actual test midstate and merkle data.

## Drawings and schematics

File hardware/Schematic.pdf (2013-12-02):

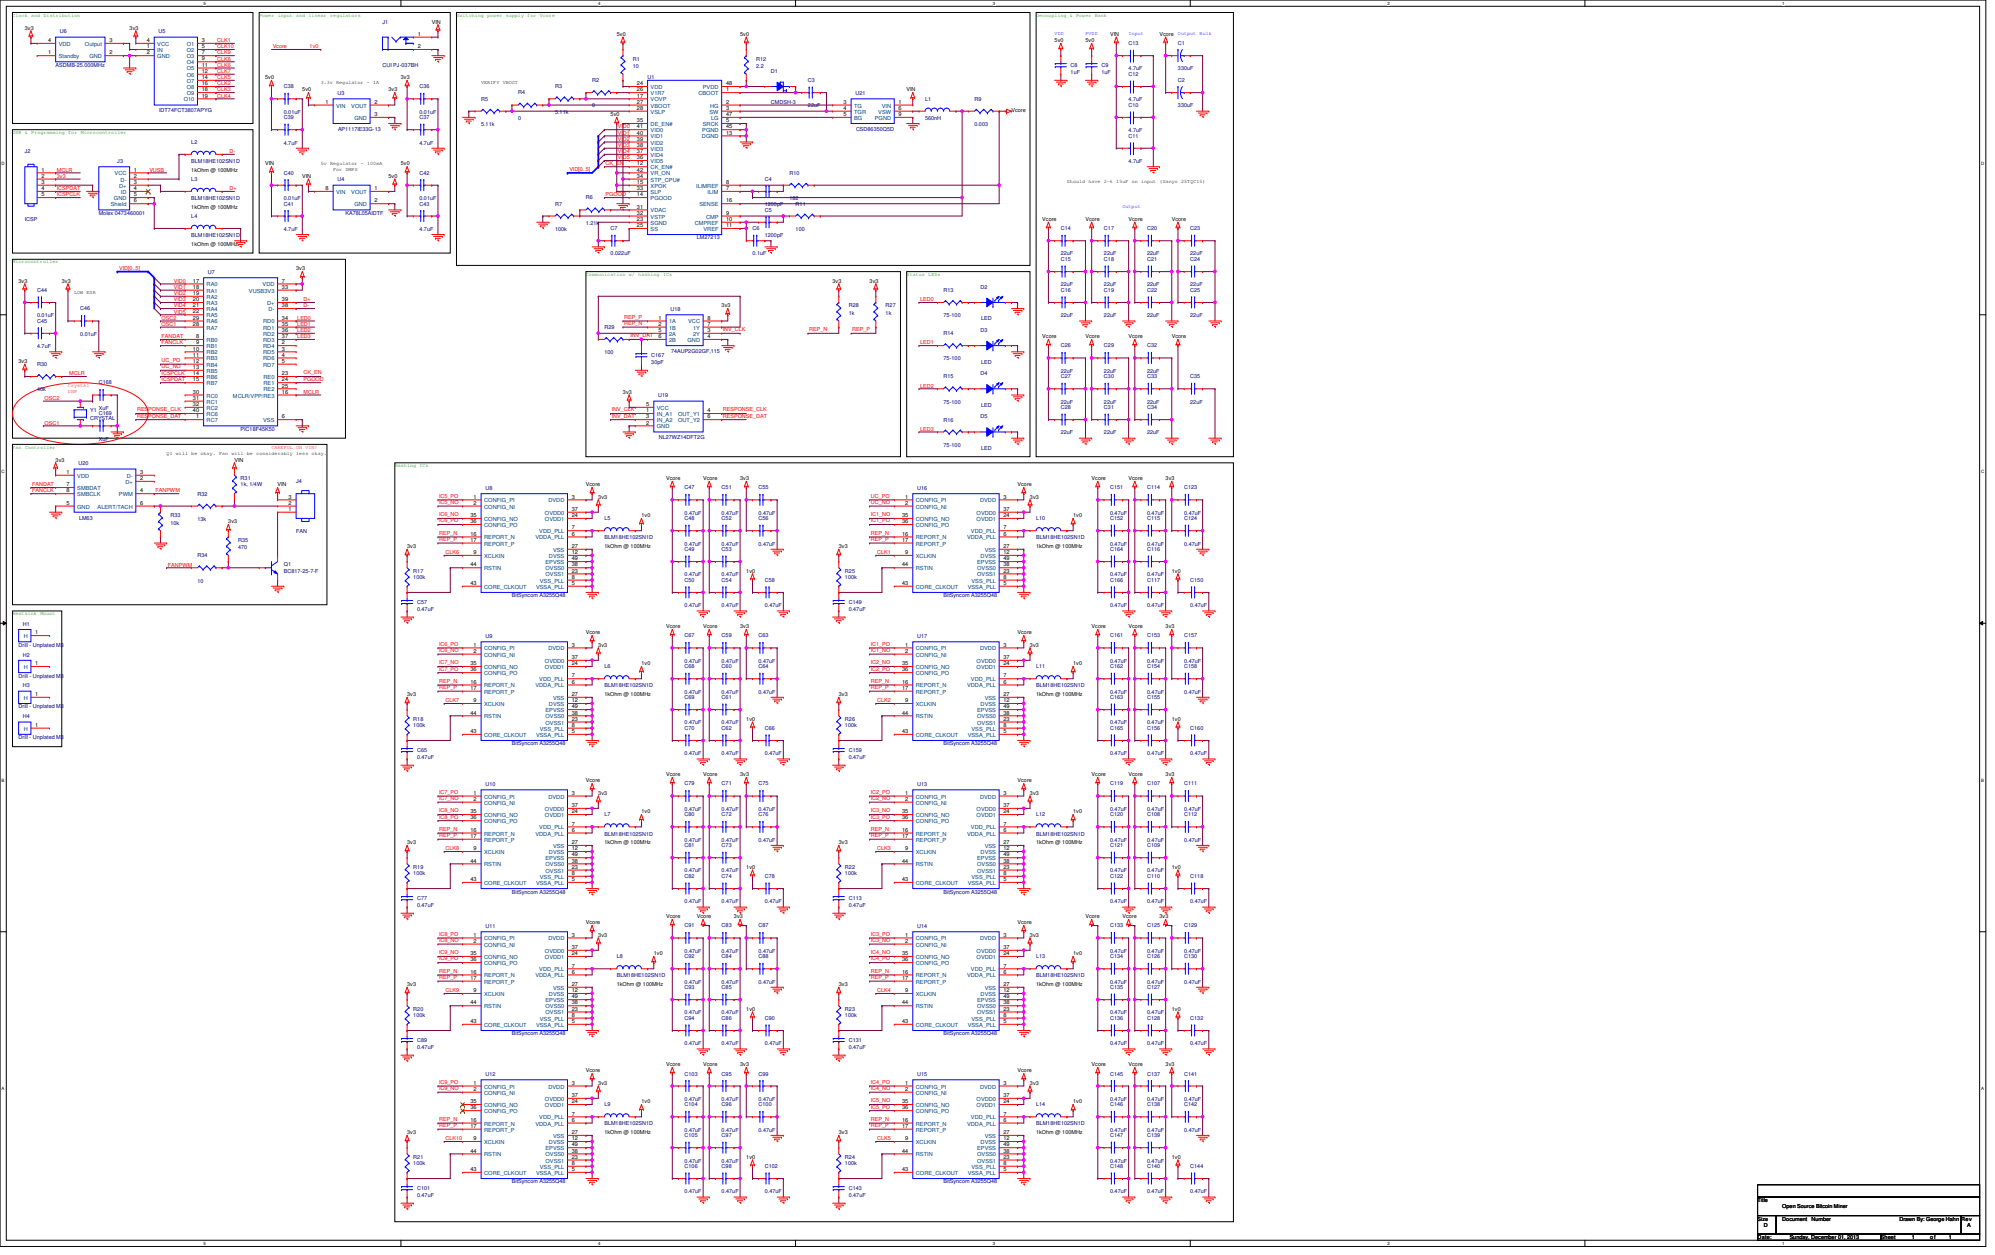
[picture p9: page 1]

Power input and linear regulators

Switching power supply for Vcore

USB & Programming for Microcontroller

Should have 2-6 15uF on input (Sanyo 25TQC15)

Q1 will be okay. Fan will be considerably less okay.

Open Source Bitcoin Miner

Drawn By: George Hahn

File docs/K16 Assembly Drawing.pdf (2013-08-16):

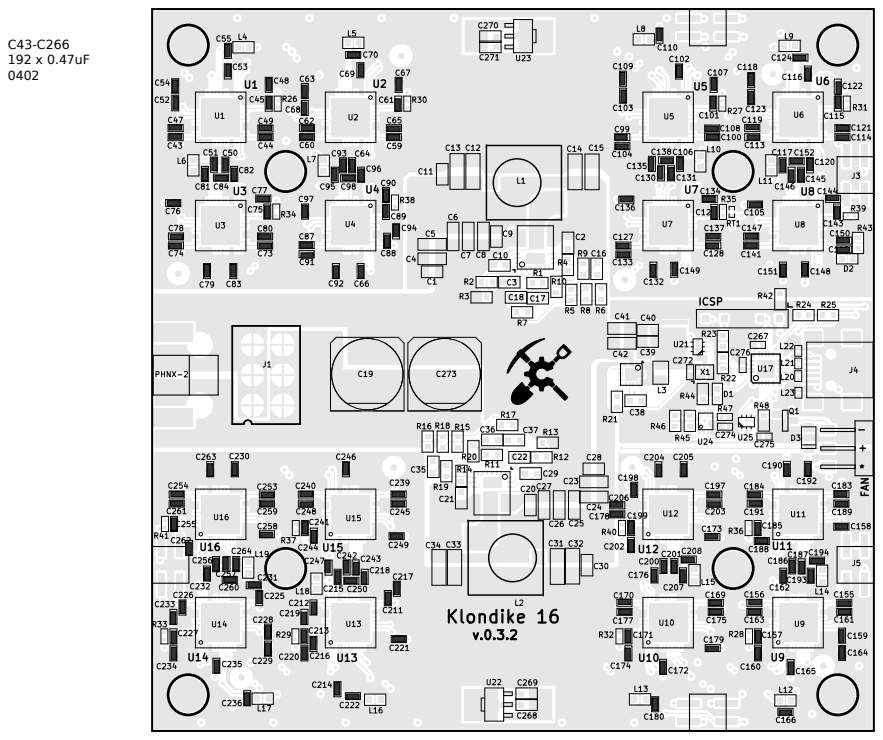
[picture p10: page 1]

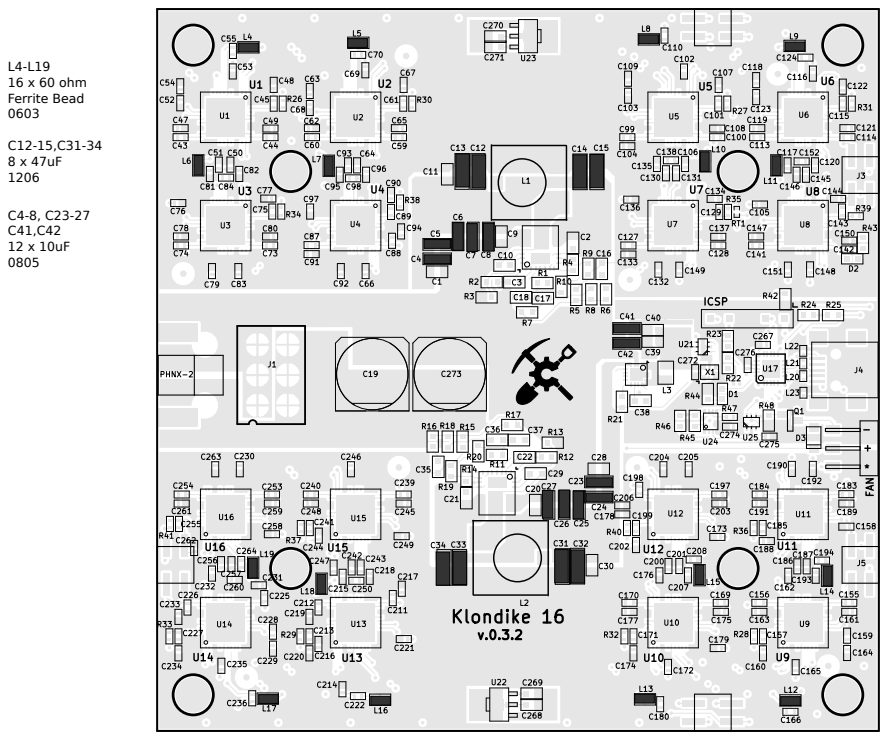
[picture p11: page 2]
L4-L19 16 x 60 ohm Ferrite Bead 0603

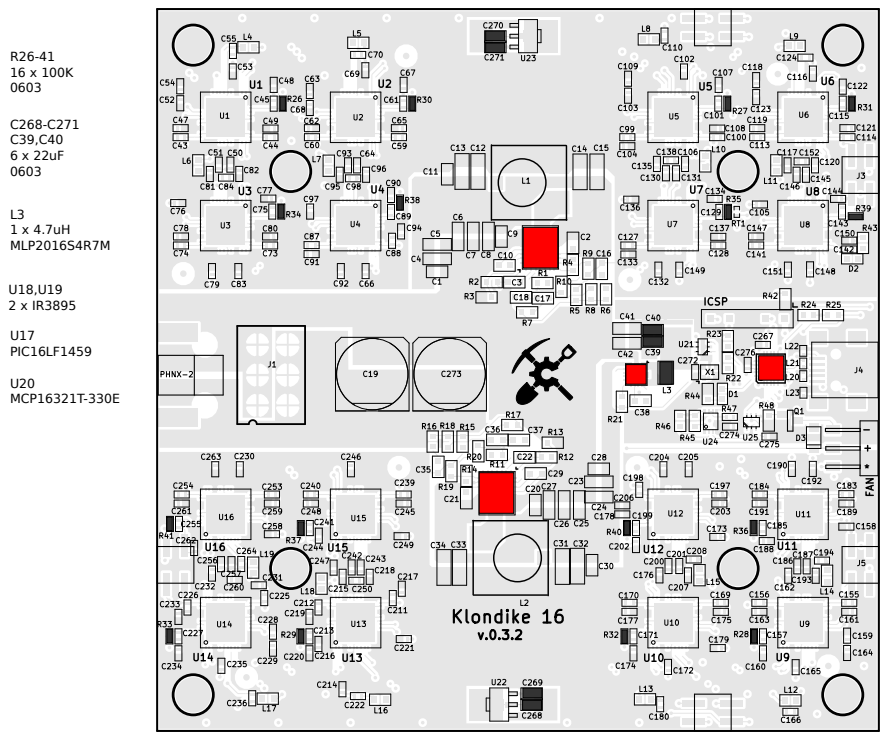
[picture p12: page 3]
L3 1 x 4.7uH MLP2016S4R7M; U17 PIC16LF1459; U20 MCP16321T-330E

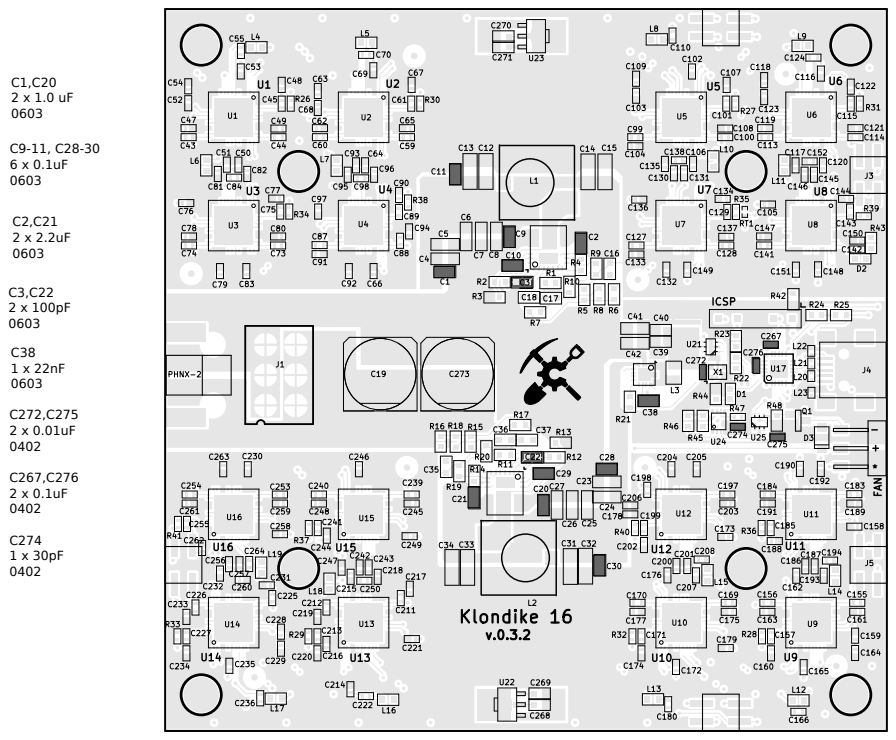
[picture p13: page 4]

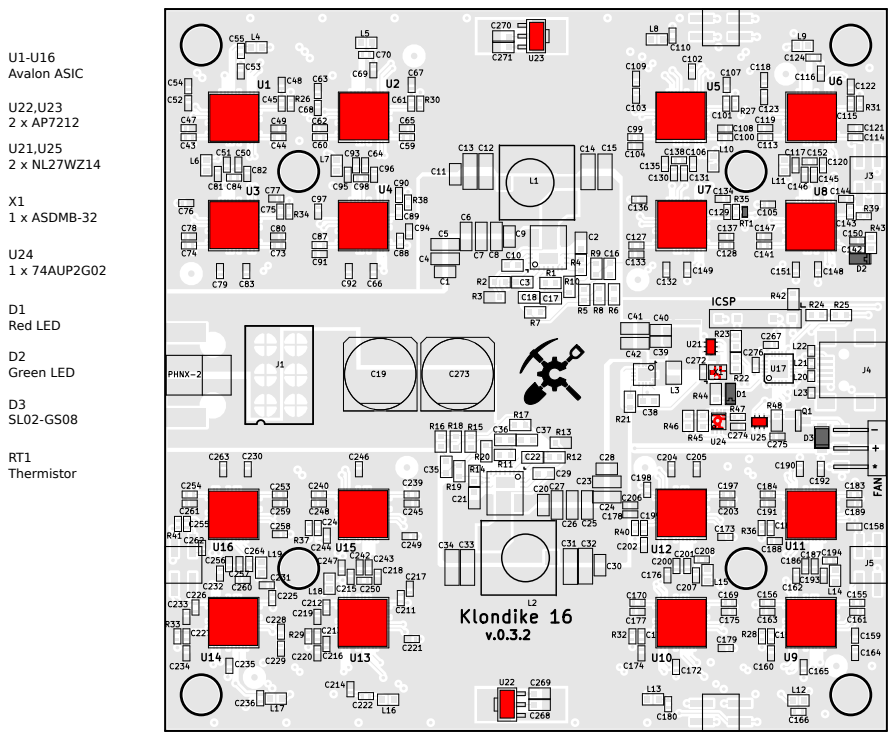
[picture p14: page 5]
U1-U16 Avalon ASIC; X1 1 x ASDMB-32; U24 1 x 74AUP2G02; D1 Red LED; D2 Green LED; RT1 Thermistor

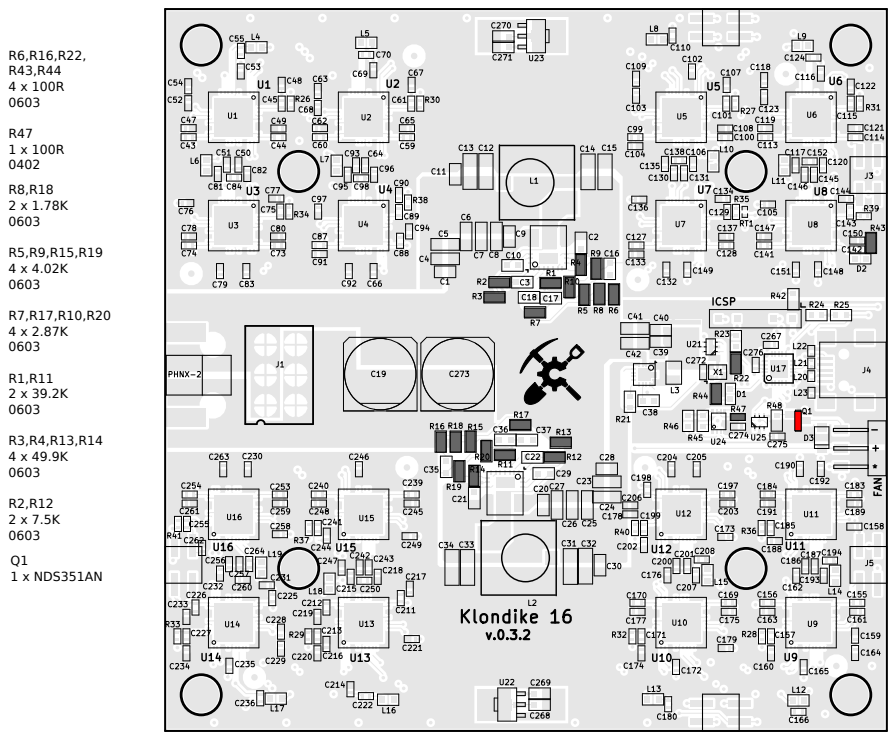
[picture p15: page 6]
Q1 1 x NDS351AN

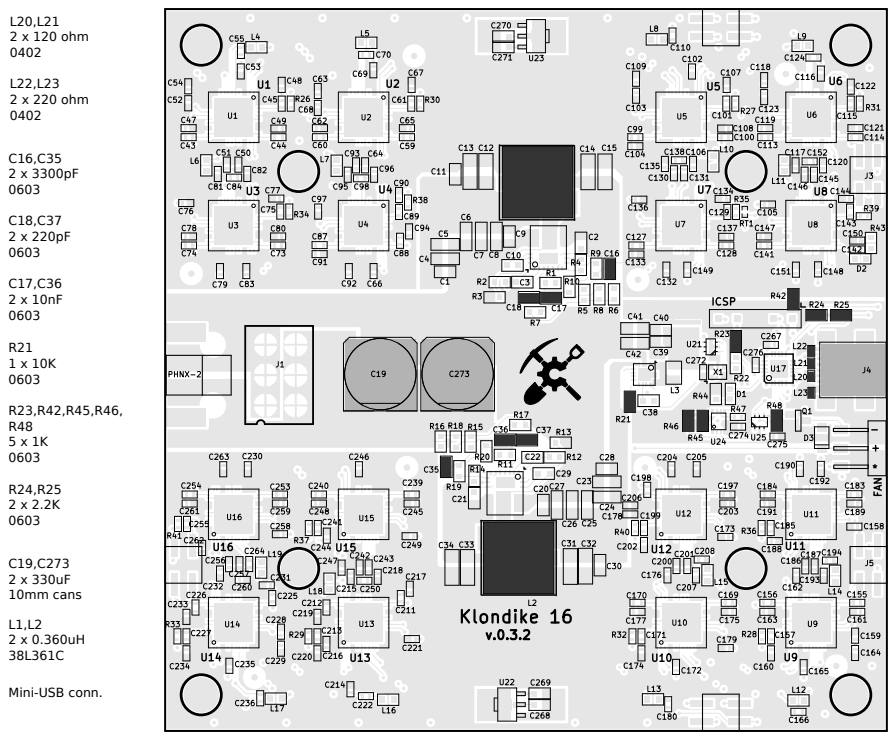
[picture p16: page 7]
L20,L21 2 x 120 ohm 0402; L22,L23 2 x 220 ohm 0402; C19,C273 2 x 330uF 10mm cans

Mini-USB conn.

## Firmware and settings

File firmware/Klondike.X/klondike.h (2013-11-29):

/********
 * Klondike ASIC Miner - klondike.h - data structures and function prototypes 
 * 
 * (C) Copyright 2013 Chris Savery. 
 *
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
 */

#ifndef KLONDIKE_H
#define KLONDIKE_H

#ifdef  __cplusplus
extern "C" {
#endif

#define FWPWD               "KlondikeRocks"

#define MASTER_ADDRESS      0x00
#define MAX_WORK_COUNT      4   // must be binary multiple
#define WORKMASK            MAX_WORK_COUNT-1
#define MAX_RESULT_COUNT    2
#define USB_RECORD_SIZE     15

// set values for ASIC PLL, we use R=16 N=Freq in MHz
#define WORK_TICKS          16384   // 2^32 total / 2^18 hashes per tick
#define TICK_TOTAL          12292   // 2^18 / 21.33uS TMR0 period (adjusted down for push time)
#define CLOCK_R_VALUE       16
#define DEFAULT_HASHCLOCK   256
#define CLOCK_NOCHG_MASK    0x00000002
#define CLOCK_LOW_CHG       0x00030007
#define CLOCK_HALF_CHG      0x00030017
#define CLOCK_HIGH_CFG      0x00000172
#define MIN_HASH_CLOCK      128
#define HALF_HASH_CLOCK     250
#define MAX_HASH_CLOCK      450

// default temp/fan values
#define DEFAULT_TEMP_TARGET     60 
#define DEFAULT_TEMP_CRITICAL   80 
#define DEFAULT_FAN_TARGET      230 // is 90%

// number of hashes to delay results while test work pushed
// 390uS push time @ 256 MHz startup clock = 99840 hashes
#define DETECT_DELAY_COUNT  109980
#define GOOD_NONCE          0xe3d69bc9
#define GOOD_MIDSTATE       { 0x5fddb5bc,0x00bdafd2,0x144684c7,0x19c68fa2,0x27d0a8e3,0x34ad84b2,0xa92c66be,0x3e99a4fd }
#define GOOD_DATA           { 0xf64684bb,0x51bc1508,0x1a011337 }

// for controlling how bits are adjusted per bank
#define DATA_ZERO   0x48
#define DATA_ONE    0x90
#define DATA_SPLIT  0x50

typedef struct _id {
    BYTE version;
    char product[7];    
    DWORD serial;
} IDENTITY;

typedef struct _workstatus {
    BYTE State;
    BYTE ChipCount;
    BYTE SlaveCount;
    BYTE WorkQC;
    BYTE WorkID;
    BYTE Temp;
    BYTE FanSpeed;
    BYTE ErrorCount;
    WORD HashCount, MaxCount;
    BYTE Noise;
} WORKSTATUS;

typedef struct _workcfg {
    WORD HashClock;
    BYTE TempTarget, TempCritical;
    BYTE FanTarget, pad;
} WORKCFG;

typedef struct _worktask {
    BYTE WorkID;
    DWORD MidState[8];
    DWORD Merkle[3];
} WORKTASK;

typedef struct _i2c {
    BYTE Next : 5;
    BYTE Slave : 1;
    BYTE Master : 1;
} I2CSTATE;

#define I2C_READ        1
#define I2C_WRITE       10
#define I2C_SLAVE       13

void ProcessCmd(char *cmd);
void AsicPushWork(void);

void CheckFanSpeed(void);
void DetectAsics(void);

void ResultRx(void);
void WorkTick(void);
void UpdateTemp(void);
void UpdateFanSpeed(void);

void I2CRelay(char *data, BYTE count);
void I2CPoll(void);
void I2CDetect(void);
void I2CRead(void);
void I2CWrite(void);
void I2CSlave(void);

void InitI2CSlave(void);
void InitI2CMaster(void);
void InitFAN(void);
void InitTempSensor(void);
void InitWorkTick(void);
void InitResultRx(void);

void SendAsicData(WORKTASK *work, BYTE split);
void Send32(void);
void AsicPreCalc(WORKTASK *work);

void SendCmdReply(char *cmd, BYTE *ReplyBuf, BYTE count);

#ifdef  __cplusplus
}
#endif

#define CLOCK_FREQ      48000000

// PIC Pin Allocations
#define LED0             LATDbits.LATD3 // LED 1 - D3
#define LED1             LATDbits.LATD2 // LED 2 - D2
#define LED2             LATDbits.LATD1 // LED 3 - D1
#define LED3             LATDbits.LATD0 // LED 4 - D0

#define InitLEDs()            \
    {                         \
        TRISDbits.TRISD3 = 0; \
        TRISDbits.TRISD3 = 0; \
        TRISDbits.TRISD3 = 0; \
        TRISDbits.TRISD3 = 0; \
        LED0 = 1;             \
        LED1 = 1;             \
        LED2 = 1;             \
        LED3 = 1;             \\\
    }

#define PASTE(first, secod) first ## secod
#define LED_On(LEDUM)   PASTE(LED, LEDUM) = 1;
#define LED_Off(LEDUM)       PASTE(LED, LEDUM) = 0;
#define LED_Toggle(LEDUM)    PASTE(LED, LEDUM) = !PASTE(LED, LEDUM);

#define MIN_FAN_SPEED   64
#define FAN_PWM         LATCbits.LATC5
#define FAN_TRIS        TRISCbits.TRISC5
#define FAN_Speed(x)    { PWM1DCH = x; }
#define TACH_FACTOR     87890	// rpm = TACH_FACTOR / count @ 170uS each

#define TEMP_INTERNAL   29
#define TEMP_THERMISTOR 6
#define THERM_TRIS      TRISCbits.TRISC2
#define TEMP_INIT       { asm("BSF FVRCON,4");asm("BSF FVRCON,5"); }

#define I2C_TRIS_DATA   TRISBbits.TRISB4
#define I2C_TRIS_CLK    TRISBbits.TRISB6
#define I2C_DATA        LATBbits.LATB4
#define I2C_CLK         LATBbits.LATB6

#define HASH_CLK_EN     LATAbits.LATA4
#define HASH_CLK_TRIS   TRISAbits.TRISA4

#define HASH_TRIS_0P    TRISCbits.TRISC7
#define HASH_TRIS_0N    TRISCbits.TRISC6
#define HASH_TRIS_1P    TRISCbits.TRISC4
#define HASH_TRIS_1N    TRISCbits.TRISC3
#define HASH_IDLE()     LATC = 0xD8;

#define RESET_RX()      { RCSTAbits.SPEN = 0;RCSTAbits.SPEN = 1;ResultQC = 0; }
#define INPUT_PIN 1
#define OUTPUT_PIN 0

#define  UART_PIN       LATBbits.LATB7
#define  TRIS_UART      TRISBbits.TRISB7
#define _XTAL_FREQ      48000000

#endif  /* KLONDIKE_H */

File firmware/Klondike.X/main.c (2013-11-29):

/********
 * 
 *  Klondike ASIC Miner - main.c - firmware USB support and control loop
 * 
 * (C) Copyright 2013 Chris Savery. 
 *
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
 * Portions Derived from Microchip LPC Dev Kit and USB stack code 
 * are covered under their own license from Microchip and not included
 * in the open source license as other source code. 
 * 
 * Supports only PIC16LF1459 processor.
 */

#include "GenericTypeDefs.h"
#include "Compiler.h"
#include "USB/usb.h"
#include "USB/usb_function_generic.h"
#include "HardwareProfile.h"
#include "klondike.h"

// TODO: Config bits
#if defined (USE_INTERNAL_OSC)  //Definition in the hardware profile
    //__CONFIG(FOSC_INTOSC & WDTE_OFF & PWRTE_ON & MCLRE_OFF & CP_OFF & BOREN_ON & CLKOUTEN_OFF & IESO_OFF & FCMEN_OFF);
    //__CONFIG(WRT_OFF & CPUDIV_NOCLKDIV & USBLSCLK_48MHz & PLLMULT_3x & PLLEN_ENABLED & STVREN_ON &  BORV_LO & LPBOR_OFF & LVP_OFF);
#else
    __CONFIG(FOSC_HS & WDTE_OFF & PWRTE_ON & MCLRE_OFF & CP_OFF & BOREN_ON & CLKOUTEN_OFF & IESO_OFF & FCMEN_OFF);
    __CONFIG(WRT_OFF & CPUDIV_NOCLKDIV & USBLSCLK_48MHz & PLLMULT_4x & PLLEN_ENABLED & STVREN_ON &  BORV_LO & LPBOR_OFF & LVP_OFF);
#endif

#define IN_DATA_BUFFER_ADDRESS 0x2140
#define OUT_DATA_BUFFER_ADDRESS 0x2190
#define IN_DATA_BUFFER_ADDRESS_TAG @IN_DATA_BUFFER_ADDRESS
#define OUT_DATA_BUFFER_ADDRESS_TAG @OUT_DATA_BUFFER_ADDRESS 

unsigned char INPacket[USBGEN_EP_SIZE] IN_DATA_BUFFER_ADDRESS_TAG;      //User application buffer for sending IN packets to the host
unsigned char OUTPacket[USBGEN_EP_SIZE] OUT_DATA_BUFFER_ADDRESS_TAG;    //User application buffer for receiving and holding OUT packets sent from the host

USB_HANDLE USBGenericOutHandle;  //USB handle.  Must be initialized to 0 at startup.
USB_HANDLE USBGenericInHandle;   //USB handle.  Must be initialized to 0 at startup.

BYTE WQI, WQX;

extern WORKSTATUS Status;
extern BYTE SlaveAddress;
extern I2CSTATE I2CState;
extern BYTE I2CCount;

/** P R I V A T E  P R O T O T Y P E S ***************************************/
static void InitializeSystem(void);
void ProcessIO(void);
void USBDeviceTasks(void);
void USBCBSendResume(void);
void UserInit(void);

void SendCmdReply(char *cmd, BYTE *ReplyBuf, BYTE count);

void interrupt ISRCode()
{
    //if(RCIF)
    //if(IOCBF)
    //    ResultRx();
    //if(TMR0IF)
    //    WorkTick();
    //if(RCIF)
    //    ResultRx();
    //if(TMR1GIF)
    //    UpdateFanSpeed();
    /*if(BCL1IF) {
        BCL1IF = 0; I2CState.Next = 0;
    }
    if(SSP1IF) {
        SSP1IF = 0;
        if(I2CState.Slave)
            I2CSlave();
        else if(I2CState.Next < I2C_WRITE) // split because not enough contigous code space
            I2CRead();
        else
            I2CWrite();
    }*/
    #if defined(USB_INTERRUPT)
        USBDeviceTasks();
    #endif
}

int main(void)
{   
    InitializeSystem();

    while(1)
    {
        #if defined(USB_INTERRUPT)
            //if(USB_BUS_SENSE && (USBGetDeviceState() == DETACHED_STATE))
            //{
                USBDeviceAttach();              
            //}
        #endif

        /*if(USBDeviceState < CONFIGURED_STATE) {
            if(!I2CState.Slave)
                InitI2CSlave();
            }
        else if(!I2CState.Master)
            InitI2CMaster();*/

        #if defined(USB_POLLING)
    // Check bus status and service USB interrupts.
        USBDeviceTasks(); // Interrupt or polling method.  If using polling, must call
                          // this function periodically.  This function will take care
                          // of processing and responding to SETUP transactions 
                          // (such as during the enumeration process when you first
                          // plug in).  USB hosts require that USB devices should accept
                          // and process SETUP packets in a timely fashion.  Therefore,
                          // when using polling, this function should be called 
                          // regularly (such as once every 1.8ms or faster** [see 
                          // inline code comments in usb_device.c for explanation when
                          // "or faster" applies])  In most cases, the USBDeviceTasks() 
                          // function does not take very long to execute (ex: <100 
                          // instruction cycles) before it returns.
        #endif
        
        if(TMR0IF)
            WorkTick();

        if(Status.State == 'P'){
            AsicPushWork();
        }
                      
        ProcessIO();  
              
    }//end while
}//end main

static void InitializeSystem(void)
{
    // all pins digital mode, except RC2, which has a Thermistor on it
    ANSELA = 0x00;
    ANSELB = 0x00;
    ANSELC = 0x04;  

    #if defined (USE_INTERNAL_OSC)
        OSCTUNE = 0;
        OSCCON = 0xFC;          //16MHz HFINTOSC with 3x PLL enabled (48MHz operation)
        ACTCON = 0x90;          //Enable active clock tuning with USB
    #endif

    USBGenericOutHandle = 0;
    USBGenericInHandle = 0;
    WQI = WQX = 0;
    
    UserInit();

    USBDeviceInit();    //usb_device.c.  Initializes USB module SFRs and firmware
                        //variables to known states.
}//end InitializeSystem


void UserInit(void)
{
    InitLED();
    InitTempSensor();
    InitFAN();
    InitWorkTick();
    //InitI2CMaster();
    InitResultRx();
    DetectAsics();

}//end UserInit

void ProcessIO(void)
{   
  
    if((USBDeviceState < CONFIGURED_STATE)||(USBSuspendControl==1)) return;

    /*if(USBGetDeviceState() == DETACHED_STATE) {
        if(I2CCount > 0) {
            ProcessCmd(OUTPacket);
            I2CCount = 0;
            }
    }
    else*/
    if(!USBHandleBusy(USBGenericOutHandle)) {
        //if( OUTPacket[1] != MASTER_ADDRESS )
        //    I2CRelay(OUTPacket, USBGEN_EP_SIZE);
        //else
            ProcessCmd(OUTPacket);
    USBGenericOutHandle = USBGenRead(USBGEN_EP_NUM, (BYTE*)&OUTPacket, USBGEN_EP_SIZE);
    }

    if(WQI != WQX && !USBHandleBusy(USBGenericInHandle)) {
        USBGenericInHandle = USBGenWrite(USBGEN_EP_NUM, (BYTE*)&INPacket[WQX*USB_RECORD_SIZE], USB_RECORD_SIZE);
        WQX = (WQX+1) & 3;
    }
} //end ProcessIO

void SendCmdReply(char *cmd, BYTE *data, BYTE count)
{
    if(WQI*USB_RECORD_SIZE + count + 2 < USBGEN_EP_SIZE) {
        INPacket[WQI*USB_RECORD_SIZE] = cmd[0];
        INPacket[WQI*USB_RECORD_SIZE + 1] = SlaveAddress;
        for(BYTE n=0; n < count; n++)
            INPacket[WQI*USB_RECORD_SIZE + n + 2] = data[n];
        WQI = (WQI+1) & 3;
    }

    //if(USBDeviceState < CONFIGURED_STATE) {
    //    I2CCount = count+2;
    //}
    //else


}


// ******************************************************************************************************
// ************** USB Callback Functions ****************************************************************
// ******************************************************************************************************
// The USB firmware stack will call the callback functions USBCBxxx() in response to certain USB related
// events.  For example, if the host PC is powering down, it will stop sending out Start of Frame (SOF)
// packets to your device.  In response to this, all USB devices are supposed to decrease their power
// consumption from the USB Vbus to <2.5mA each.  The USB module detects this condition (which according
// to the USB specifications is 3+ms of no bus activity/SOF packets) and then calls the USBCBSuspend()
// function.  You should modify these callback functions to take appropriate actions for each of these
// conditions.  For example, in the USBCBSuspend(), you may wish to add code that will decrease power
// consumption from Vbus to <2.5mA (such as by clock switching, turning off LEDs, putting the
// microcontroller to sleep, etc.).  Then, in the USBCBWakeFromSuspend() function, you may then wish to
// add code that undoes the power saving things done in the USBCBSuspend() function.

// The USBCBSendResume() function is special, in that the USB stack will not automatically call this
// function.  This function is meant to be called from the application firmware instead.  See the
// additional comments near the function.

// Note *: The "usb_20.pdf" specs indicate 500uA or 2.5mA, depending upon device classification. However,
// the USB-IF has officially issued an ECN (engineering change notice) changing this to 2.5mA for all 
// devices.  Make sure to re-download the latest specifications to get all of the newest ECNs.

/******************************************************************************
 * Function:        void USBCBSuspend(void)
 *
 * PreCondition:    None
 *
 * Input:           None
 *
 * Output:          None
 *
 * Side Effects:    None
 *
 * Overview:        Call back that is invoked when a USB suspend is detected
 *
 * Note:            None
 *****************************************************************************/
void USBCBSuspend(void)
{
    //Example power saving code.  Insert appropriate code here for the desired
    //application behavior.  If the microcontroller will be put to sleep, a
    //process similar to that shown below may be used:
    
    //ConfigureIOPinsForLowPower();
    //SaveStateOfAllInterruptEnableBits();
    //DisableAllInterruptEnableBits();
    //EnableOnlyTheInterruptsWhichWillBeUsedToWakeTheMicro();   //should enable at least USBActivityIF as a wake source
    //Sleep();
    //RestoreStateOfAllPreviouslySavedInterruptEnableBits();    //Preferrably, this should be done in the USBCBWakeFromSuspend() function instead.
    //RestoreIOPinsToNormal();                                  //Preferrably, this should be done in the USBCBWakeFromSuspend() function instead.

    //IMPORTANT NOTE: Do not clear the USBActivityIF (ACTVIF) bit here.  This bit is 
    //cleared inside the usb_device.c file.  Clearing USBActivityIF here will cause 
    //things to not work as intended.   
    
}

/******************************************************************************
 * Function:        void USBCBWakeFromSuspend(void)
 *
 * PreCondition:    None
 *
 * Input:           None
 *
 * Output:          None
 *
 * Side Effects:    None
 *
 * Overview:        The host may put USB peripheral devices in low power
 *                  suspend mode (by "sending" 3+ms of idle).  Once in suspend
 *                  mode, the host may wake the device back up by sending non-
 *                  idle state signalling.
 *                  
 *                  This call back is invoked when a wakeup from USB suspend 
 *                  is detected.
 *
 * Note:            None
 *****************************************************************************/
void USBCBWakeFromSuspend(void)
{
    // If clock switching or other power savings measures were taken when
    // executing the USBCBSuspend() function, now would be a good time to
    // switch back to normal full power run mode conditions.  The host allows
    // a few milliseconds of wakeup time, after which the device must be 
    // fully back to normal, and capable of receiving and processing USB
    // packets.  In order to do this, the USB module must receive proper
    // clocking (IE: 48MHz clock must be available to SIE for full speed USB
    // operation).
}

/********************************************************************
 * Function:        void USBCB_SOF_Handler(void)
 *
 * PreCondition:    None
 *
 * Input:           None
 *
 * Output:          None
 *
 * Side Effects:    None
 *
 * Overview:        The USB host sends out a SOF packet to full-speed
 *                  devices every 1 ms. This interrupt may be useful
 *                  for isochronous pipes. End designers should
 *                  implement callback routine as necessary.
 *
 * Note:            None
 *******************************************************************/
void USBCB_SOF_Handler(void)
{
    // No need to clear UIRbits.SOFIF to 0 here.
    // Callback caller is already doing that.
}

/*******************************************************************
 * Function:        void USBCBErrorHandler(void)
 *
 * PreCondition:    None
 *
 * Input:           None
 *
 * Output:          None
 *
 * Side Effects:    None
 *
 * Overview:        The purpose of this callback is mainly for
 *                  debugging during development. Check UEIR to see
 *                  which error causes the interrupt.
 *
 * Note:            None
 *******************************************************************/
void USBCBErrorHandler(void)
{
    // No need to clear UEIR to 0 here.
    // Callback caller is already doing that.

    // Typically, user firmware does not need to do anything special
    // if a USB error occurs.  For example, if the host sends an OUT
    // packet to your device, but the packet gets corrupted (ex:
    // because of a bad connection, or the user unplugs the
    // USB cable during the transmission) this will typically set
    // one or more USB error interrupt flags.  Nothing specific
    // needs to be done however, since the SIE will automatically
    // send a "NAK" packet to the host.  In response to this, the
    // host will normally retry to send the packet again, and no
    // data loss occurs.  The system will typically recover
    // automatically, without the need for application firmware
    // intervention.
    
    // Nevertheless, this callback function is provided, such as
    // for debugging purposes.
}


/*******************************************************************
 * Function:        void USBCBCheckOtherReq(void)
 *
 * PreCondition:    None
 *
 * Input:           None
 *
 * Output:          None
 *
 * Side Effects:    None
 *
 * Overview:        When SETUP packets arrive from the host, some
 *                  firmware must process the request and respond
 *                  appropriately to fulfill the request.  Some of
 *                  the SETUP packets will be for standard
 *                  USB "chapter 9" (as in, fulfilling chapter 9 of
 *                  the official USB specifications) requests, while
 *                  others may be specific to the USB device class
 *                  that is being implemented.  For example, a HID
 *                  class device needs to be able to respond to
 *                  "GET REPORT" type of requests.  This
 *                  is not a standard USB chapter 9 request, and 
 *                  therefore not handled by usb_device.c.  Instead
 *                  this request should be handled by class specific 
 *                  firmware, such as that contained in usb_function_hid.c.
 *
 * Note:            None
 *****************************************************************************/
void USBCBCheckOtherReq(void)
{
    USBCheckVendorRequest();
}//end


/*******************************************************************
 * Function:        void USBCBStdSetDscHandler(void)
 *
 * PreCondition:    None
 *
 * Input:           None
 *
 * Output:          None
 *
 * Side Effects:    None
 *
 * Overview:        The USBCBStdSetDscHandler() callback function is
 *                  called when a SETUP, bRequest: SET_DESCRIPTOR request
 *                  arrives.  Typically SET_DESCRIPTOR requests are
 *                  not used in most applications, and it is
 *                  optional to support this type of request.
 *
 * Note:            None
 *****************************************************************************/
void USBCBStdSetDscHandler(void)
{
    // Must claim session ownership if supporting this request
}//end


/******************************************************************************
 * Function:        void USBCBInitEP(void)
 *
 * PreCondition:    None
 *
 * Input:           None
 *
 * Output:          None
 *
 * Side Effects:    None
 *
 * Overview:        This function is called when the device becomes
 *                  initialized, which occurs after the host sends a
 *                  SET_CONFIGURATION (wValue not = 0) request.  This 
 *                  callback function should initialize the endpoints 
 *                  for the device's usage according to the current 
 *                  configuration.
 *
 * Note:            None
 *****************************************************************************/
void USBCBInitEP(void)
{
    //Enable the application endpoints
    USBEnableEndpoint(USBGEN_EP_NUM,USB_OUT_ENABLED|USB_IN_ENABLED|USB_HANDSHAKE_ENABLED|USB_DISALLOW_SETUP);
    //Arm the application OUT endpoint, so it can receive a packet from the host
    USBGenericOutHandle = USBGenRead(USBGEN_EP_NUM,(BYTE*)&OUTPacket,USBGEN_EP_SIZE);
}
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

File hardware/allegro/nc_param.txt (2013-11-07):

INTEGER-PLACES         2
DECIMAL-PLACES         4
X-OFFSET               0.000000
Y-OFFSET               0.000000
FEEDRATE               1
COORDINATES            ABSOLUTE
OUTPUT-UNITS           ENGLISH
TOOL-ORDER             INCREASING
REPEAT-CODES           NO
SUPPRESS-LEAD-ZEROES   NO
SUPPRESS-TRAIL-ZEROES  NO
SUPPRESS-EQUAL         NO
TOOL-SELECT            YES
OPTIMIZE_DRILLING      NO
ENHANCED_EXCELLON      YES
TAPE-FILE              C:/USERS/GEORGE/DOCUMENTS/GITHUB/AVALON/HARDWARE/allegro/drills.drl
HEADER                 none
LEADER                 12
CODE                   ASCII
SEPARATE               NO
SEPARATE-ROUTING       NO
DRILLING               BY-LAYER
BACKDRILL              NO
CAVITY                 NO

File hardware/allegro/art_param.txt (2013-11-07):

DEVICE-TYPE           GERBER_RS274X
OUTPUT-UNITS          INCHES
FILM-SIZE             2400000 1600000
FORMAT                2.5
ABORT-ON-ERROR        YES
SCALE                 1
SUPPRESS-LEAD-ZEROES  YES
SUPPRESS-TRAIL-ZEROES NO
SUPPRESS-EQUAL        YES
UNDEF-APT-CONT        NO

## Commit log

2013-05-02 Added preliminary parts list
    [Parts List.ods]
2013-05-03 Updated parts list with missed resistors
    [Parts List.ods]
2013-05-07 updated and moved part list, chgd oscillator, caps
    [Parts List.ods]
2013-05-08 added test power.brd and 3d K16 image
    [power.brd, power.sch]
2013-05-09 update test power board
    [power.brd, power.sch]
2013-05-09 updated test power board
    [power.brd, power.sch]
2013-05-09 reversed last changes
    [power.brd]
2013-05-09 re-did analog gnd bridge, added thermal vias
    [power.brd]
2013-05-09 added test power gerbers
    [power.sch]
2013-05-10 updated parts list, power brd, Klego
    [Parts List.ods, power.brd]
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2013-05-11 update parts list LEDs,Thermistor,LDO
    [Parts List.ods]
2013-05-11 added incomplete gerber outputs for k16
    [k16-NPTH.drl, k16.drl]
2013-05-14 update parts list, chg names, add K1, update datasheets
    [K1 Parts List.ods, K16 Parts List.ods, Parts List.ods]
2013-05-14 updated k16 plot files
    [k16-B_Cu.gbl, k16-B_Mask.gbs, k16-Dwgs_User.gbr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]
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2013-05-15 updated k16 plots with AGND bridge
    [k16-B_Cu.gbl, k16-B_Mask.gbs, k16-Dwgs_User.gbr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]
2013-05-15 updated k16 plots - 5x5 via grids
    [k16-B_Cu.gbl, k16-B_Mask.gbs, k16-Dwgs_User.gbr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]
2013-05-15 fixed errors in AVDD tracks
    [k16-B_Cu.gbl, k16-B_Mask.gbs, k16-Dwgs_User.gbr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]
2013-05-15 updated k1 parts list
    [K1 Parts List.ods]
2013-05-15 updated K16, k1 parts, added k1 plots
    [K1 Parts List.ods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]
2013-05-16 update k16 parts list with summary
    [K16 Parts List.ods]
2013-05-16 update k16,k1 fix missing caps, add fiducials
    [K1 Parts List.ods, K16 Parts List.ods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]
2013-05-17 updated k16 for data protocol
    [K16 Parts List.ods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]
2013-05-18 updated k16.mod and plots - paste layer
    [k16-B_Cu.gbl, k16-B_Mask.gbs, k16-Dwgs_User.gbr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]
2013-05-18 added silkscreen text, and small fixes
    [k16-B_Cu.gbl, k16-B_Mask.gbs, k16-Dwgs_User.gbr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]
2013-05-19 update K16, K1 boards and docs
    [K1 Parts List.ods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]
2013-05-19 updated k16 with png and svg images
    [nano-B_Cu.gbl, nano-B_Mask.gbs, nano-Dwgs_User.gbr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]
2013-05-21 add klego on k16, chg hole sizes
    [K1 Parts List.ods, K16 Parts List.ods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]
2013-05-22 updated K16 standoff clearances, k1 parts list
    [K1 Parts List.ods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]
2013-05-24 update k16 parts placement, add thermal svg
    [k16-B_Cu.gbl, k16-B_Mask.gbs, k16-Dwgs_User.gbr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]
2013-05-30 updated k16 with resistor, and parts list
    [K16 Parts List.ods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]
2013-06-06 Updated parts list and added VRML export files
    [K16 Parts List.ods]
2013-06-07 updated parts list for connector part code error
    [K16 Parts List.ods]
2013-06-14 initial release 0.1.0, clean up and add license to files
    [K1 Parts List.ods, K16 Parts List.ods, Klondike.X.production.obj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]
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2013-06-14 remove unused protoboard files
    [power.brd, power.sch]
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2013-06-14 update K16 parts list
    [K16 Parts List.ods]
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2013-06-16 added K1 assembly drawing
    [k16-B_Cu.gbl, k16-B_Mask.gbs, k16-Dwgs_User.gbr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]
2013-06-20 update nano design files, add fix1
    [k16.brd, nano.brd, nano.sch]
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2013-06-20 update logo and v0.2.0
    [k16.brd, nano.brd]
2013-06-21 update K16 brd for PIC VCC fix, 0.2.1
    [k16-B_Cu.gbl, k16-B_Mask.gbs, k16-Dwgs_User.gbr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]
2013-06-22 fix GND zone n/c on nano, set 1.2.1
    [nano-B_Cu.gbl, nano-B_Mask.gbs, nano-B_Paste.gbp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]
2013-06-24 update resistors, parts list, v0.2.2
    [K1 Parts List.ods, K16 Parts List.ods, Klondike.X.production.obj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]
2013-06-30 Update Tech Ref and ktemp
    [Thermistor Lookup Table.ods]
2013-07-02 update firmware and driver, create new cgminer fork
    [K16 Parts List.ods, Klondike.X.production.obj]
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2013-07-07 fixes for 300 MHz, fix K1 parts list
    [K1 Parts List.ods, nano.brd, nano.sch]
2013-07-08 added driver config option support
    [Thermistor Lookup Table.ods]
2013-07-08 prevent nonces when not state W
    [klondike.c]
2013-07-10 update K16 parts list for 1.3.0 rev coming
    [K16 Parts List.ods]
2013-07-11 updated firmware, IOC method
    [K1 Parts List.ods]
2013-07-11 fw chg, rx reset
    [klondike.c]
2013-07-15 update parts list for final beta
    [K16 Parts List.ods]
2013-07-15 beta final 0.3.0 release
    [K16 Parts List.ods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]
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2013-07-16 added QFN variant, k16q, 0.3.1
    [k16-B_Cu.gbl, k16-B_Mask.gbs, k16-Dwgs_User.gbr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]
2013-07-17 re-add phnx pwr conn
    [k16 (copy).brd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]
2013-07-17 update K1 parts, schematic
    [K1 Parts List.ods, K16 Parts List.ods, nano.sch]
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2013-07-23 update K1 to 0.3.0
    [K1 Parts List.ods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]
2013-07-23 add new K1 plot files, white 3D png
    [nano-B_Cu.gbl, nano-B_Mask.gbs, nano-B_Paste.gbp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]
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2013-07-23 removed old K1 files
    [nano2up.kicad_pcb]
2013-07-25 k1 - add logo and 2nd bottom exposed pad
    [nano-B_Cu.gbl, nano-B_Mask.gbs, nano-B_Paste.gbp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]
2013-07-25 small tweaks to K1 brd
    [nano-B_Cu.gbl, nano-B_Mask.gbs, nano-B_Paste.gbp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]
2013-08-05 fix error, K16 parts list
    [K16 Parts List.ods]
2013-08-16 update firmware for 16 chips, add dist files
    [Klondike.X.production.obj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]
2013-08-16 fix firmware to use pro mode
    [Klondike.X.production.obj]
2013-10-18 wipe out klondike hardware design
    [k16 (copy).brd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]
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2013-11-02 Initial commit of hardware
    [AVALON.DSN, AVALON.brd, cases.cfg]
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2013-11-03 Added some footprints, placed on design
    [AVALON.DSN, AVALON.brd, RES_1225.psm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]
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2013-11-04 Preliminary part placement is complete
    [AVALON.DSN, AVALON.brd]
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2013-11-04 Component placement complete, beginning layout
    [AVALON.DSN, AVALON.brd]
2013-11-04 Initial route of response pins complete
    [AVALON.brd]
2013-11-05 Routing almost done, just need to sort out the clock lines
    [AVALON.brd]
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2013-11-05 Centered thermal via arrays on IC ground pads
    [AVALON.brd]
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2013-11-05 Removed soldermask from under all hashing ICs
    [AVALON.brd]
2013-11-05 Added heatsink mounting holes
    [AVALON.DSN, AVALON.brd]
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2013-11-05 Added ferrite bead on ASIC VDD_PLL and VDDA_PLL and USB D+/D-/GND+SHLD
    [AVALON.DSN]
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2013-11-07 Commiting a bunch of junk this round, but in a rush and this has final alpha gerbers
    [AVALON.brd, art_param.txt]
2013-11-11 Fixed some DRC errors
    [AVALON.brd]
2013-11-11 Added a whole bunch of vias, regenerated gerbers
    [AVALON.brd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]
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2013-11-11 Fixing DRC errors
    [AVALON.brd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]
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2013-11-12 Final changes, ordered prototype
    [AVALON.brd]
2013-11-13 Added PASTE_TOP layer for pastemask
    [AVALON.brd]
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2013-11-15 Fix item for line 36, was a >$1 resistor
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2013-12-01 Trying to fix the footprint for D1 to no avail
    [AVALON.brd]
2013-12-01 Add soldermask over vias. Fixes #15
    [AVALON.brd]
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2013-12-02 5v->3.3v regulator instead of vin. Fixes #10.
    [AVALON.DSN, AVALON.brd]
2013-12-02 Flip connections on U3, solves #16
    [AVALON.DSN, AVALON.brd]
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

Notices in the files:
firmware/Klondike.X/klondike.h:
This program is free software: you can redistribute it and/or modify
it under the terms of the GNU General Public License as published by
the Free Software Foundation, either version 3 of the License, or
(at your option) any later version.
